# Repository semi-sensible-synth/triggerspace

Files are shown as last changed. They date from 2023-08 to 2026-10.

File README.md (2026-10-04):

# triggerspace

> **TESTED** - v0.042 works with some simple bodges (build notes below)
>
> **IN PROGRESS** - v0.5.0 removes the v0.042 bodges and adds optional RC reconstruction-cap
> sockets on the jack PCB's outputs to support alternative oscillators/sampler firmware; not yet fabricated or bench-verified (see
> [CHANGELOG.md](CHANGELOG.md))



This is a remix of the [NanoGris](https://github.com/Quinienl/NanoGris) trigger sequence generator (by Quinie), which in turn was based on the original [Grids](https://pichenettes.github.io/mutable-instruments-documentation/modules/grids/) hardware design by Mutable Instruments / Émilie Gillet, used under a Creative Commons ShareAlike 3.0 License (CC BY-SA 3.0).

The front panel looks something like this:

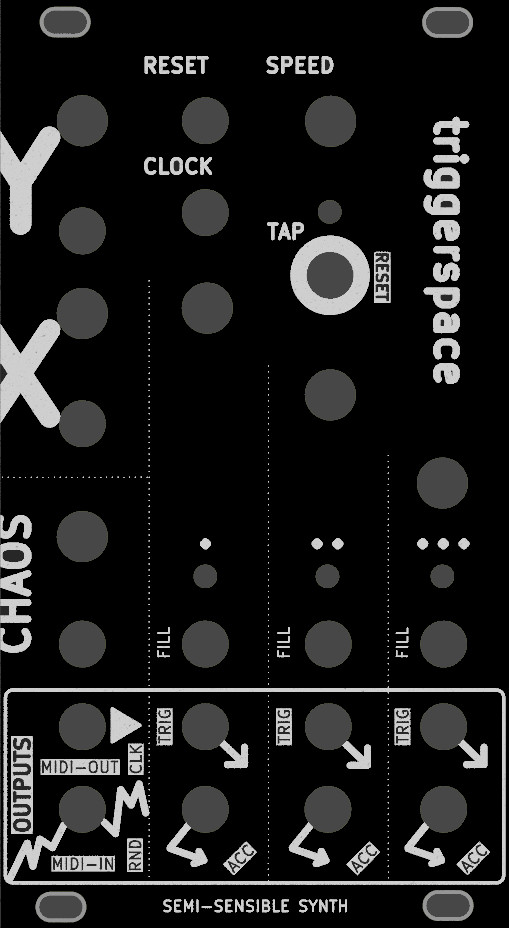
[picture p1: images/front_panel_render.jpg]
triggerspace front panel render Front panel


# Features
- Outputs three channels of 'topographic' drum triggers (kick, snare, hihat), with accent outputs
- Internal clock, with reset and swing
- External clock input, via triggers or MIDI clock
- Beat density (fill), X, Y and Chaos inputs to modify each pattern
- MIDI TRS-A output, General MIDI drum notes on channel 10
- MIDI TRS input accepts Type A and Type B (v0.5.0, [LPZW auto-crossover MIDI input](https://github.com/kay-lpzw/LPZW_TRS_MIDI))
- 38mA peak current draw on +12V rail (28mA idle)
- Experimental alternative firmwares: 6-voice oscillator [Gritty-osc](https://github.com/semi-sensible-synth/triggerspace/blob/main/firmware/Gritty-osc/README.md) and drum hit synth [Gritty-drumsynth](https://github.com/semi-sensible-synth/triggerspace/blob/main/firmware/Gritty-drumsynth/README.md)

## Firmware

_The stock Grids/NanoGris firmware is not compatible_ - use this: [Gritty-Grids firmware (triggerspace fork)](https://github.com/semi-sensible-synth/Gritty-Grids). Follow the instructions there to flash the firmware to your triggerspace module.

This Gritty-Grids fork:

- Supports modified Arduino Nano pin assignments used by _triggerspace_ hardware
- Sends General MIDI drum notes on channel 10 to MIDI-OUT (TRS-A)
  - GM MIDI (and Roland TR-8S) drum note numbers:
  ```
  Out 1:             36 (0x24, C1)  - bass/kick drum
  Out 2:             38 (0x26, D1)  - snare drum
  Out 3 (no accent): 42 (0x2a, F#1) - closed hi-hat
  Out 3 (accented):  46 (0x2e, Bb1) - open hi-hat
  ```
- Maps accents to MIDI note velocity: accented steps are sent at velocity 127 and
  unaccented steps at 90. Accented hi-hat steps also switch to the open hi-hat note (46).
  - Accents only exist in drum mode. With the clock output option on, Grids
    has a single common accent output, so that accent applies to all three drums.
  - In Euclidean mode there are no accents: every note is sent at velocity 127 as the
    closed hi-hat.
  - Set by `midi_accent_velocity` in `grids/grids.cc` (default on). When off, every note
    is sent at 127; the open/closed hi-hat switch still follows the accent. It can only
    be changed by recompiling for now.
  - Gritty-drumsynth sends MIDI notes the same way.

## Build options

### MIDI IN optocoupler (U8 / U9)

From v0.5.0 the MIDI input is the
[LPZW auto-crossover MIDI input](https://github.com/kay-lpzw/LPZW_TRS_MIDI) by Kay Knofe
of LPZW.modules.

It accepts TRS Type A and Type B cables with no switch. It works by using the two LEDs of a dual optocoupler in an 'anti-parallel' configuration across the tip and ring, each with its own 220R. Whichever way round the loop current flows, one LED lights, and the two open-collector outputs share one 1k pull-up (R47), so the Nano sees the same signal either way.

Fit one of these:

| Build | U8 (DIP-8 socket) | U9 (SOIC-8) | D7 | JP3, JP4 | Accepts |
|---|---|---|---|---|---|
| **Default** | HCPL-2630 or HCPL-2631 | not fitted | not fitted | as made (1-2 bridged) | Type A and B |
| SMD optocoupler | not fitted, no socket | HCPL-0630 or HCPL-0631 | not fitted | as made (1-2 bridged) | Type A and B |
| 6N138 (as v0.042) | 6N138 | not fitted | 1N4148 | cut 1-2, bridge 2-3 | Type A only |

- U9 sits inside U8's DIP-8 footprint on the back of the jack PCB, so fit U8 or U9,
  never both - a DIP socket would sit on top of U9. The HCPL-263x (DIP-8) and HCPL-063x
  (SOIC-8) have the same pinout.
- R46 (4.7k) is fitted in every build but only connected (through JP4) in the 6N138
  build, where it is the 6N138's base resistor. R51 is only used by the dual
  optocouplers; with a 6N138 it goes to an unconnected pin.
- D7 protects the 6N138's LED from reverse voltage. Don't fit it with a dual
  optocoupler: it would sit across one of the LEDs and take the current meant for the
  other, so Type B input would stop working.
- The HCPL-263x/063x is guaranteed to switch at 5mA LED current. A 5V MIDI 1.0 sender
  into a 220R receiver gives about 5mA, so worst-case parts are marginal (typical parts
  switch at about 2mA); 3.3V senders built to the MIDI Association's CA-33 values give
  about 7mA. The 6N138 needs only about 1.6mA, so it tolerates weaker Type A senders.

See [Jumpers](#jumpers) for JP3/JP4 to enable the 6N138 build (and other jumper settings).

### -5V reference: LM4040 or 5.1V zener (U5 / D8)

U5 (LM4040LP-5, TO-92) makes the -5V reference (`ref_5`) for the CV input offsets,
fed from -12V through R31 (10k). D8 is an alternative footprint in parallel with it for
a 5.1V zener diode (DO-35, e.g. BZX79C5V1 or 1N5231B), which worked well on a v0.042
build. Fit U5 or D8, not both.

- D8 sits inside U5's outline and is mounted upright: the diode body goes on the round
  pad with the cathode band at the top, and the bent lead goes into the square pad
  (marked K, to GND). The anode is on `ref_5`, because the reference is negative.
- R31 sets the zener current to about (12V - 5.1V) / 10k = 0.7mA. This is below the
  5-20mA test current of common 5.1V zeners, so expect a little less than 5.1V and a
  less stable voltage than the LM4040. The voltage shifts the CV input offsets slightly;
  it doesn't affect the triggers.

### +5V supply and power header (U4, JP5, JP6, J12)

The +5V rail (op amps, shift register, pots, trigger transistors) can come from one of
three sources. Use exactly one: don't connect two regulator outputs together.

| +5V source | U4, C11, C12 | JP5 | JP6 | Power cable |
|---|---|---|---|---|
| **U4 (L7805), default** | fitted | open | open | 10-pin or 16-pin |
| Nano's regulator | not fitted | bridged | open | 10-pin or 16-pin |
| Eurorack +5V | not fitted | open | bridged | 16-pin, from a PSU with +5V |

U4, C11 and C12 are marked "OPTIONAL" on the silkscreen. JP5 and JP6 are open as made.

- **Nano's regulator (JP5):** since v0.5.0 the Nano's VIN is fed from +12V, so its
  onboard 5V regulator is running anyway. JP5 connects the Nano's 5V pin (A1 pin 27) to
  the +5V rail, so that regulator supplies the whole module. The v0.042 module drew
  28-38mA from +12V in total, so the regulator dissipates about (12V - 5V) x 38mA =
  0.27W. With JP5 bridged, the Nano's USB port also powers the +5V rail when the module
  has no Eurorack power.
- **Eurorack +5V (JP6):** J12 is a 16-pin (2x8) footprint. Pins 11 and 12 are the
  Eurorack +5V rail, connected to the module's +5V rail through JP6. Pins 13-16 (CV and
  Gate buses) are not connected. With JP6 open, a 16-pin cable is safe whether or not
  the PSU provides +5V.
- **10-pin header in the 16-pin footprint:** a 2x5 header fits in J12 pins 1-10 (the
  end with the square pad, marked "RED!!" for the cable's -12V stripe), so 10-pin cables
  still work. The
  silkscreen outline is drawn for a 16-pin shrouded header; line up a 10-pin header's
  pin 1 with the square pad.

### RC reconstruction caps (CH*_CAP1)

The six 2-pin sockets next to the output jacks on the jack PCB (`CH1_CAP1`,
`CH1_ACC_CAP1`, `CH2_CAP1`, `CH2_ACC_CAP1`, `CH3_CAP1`, `CH3_ACC_CAP1`) take optional
capacitors to GND that filter the sigma-delta hiss from the Gritty-drumsynth firmware's
synthesised drum voices. Leave them empty for trigger outputs (Gritty-Grids firmware).
Values are still to be chosen (see TODO / IDEAS).

## Jumpers

Most solder jumpers (JP1-JP4) are shorted by a copper trace between their pads as made;
cut the trace with a craft knife to open them. JP5 and JP6 are open as made. Bridge pads
with solder to close a jumper. Pin
jumpers (J) are 2.54mm headers for jumper caps. Pin 1 of each header is the square pad.
The silkscreen next to each header repeats its settings.

Firmware and jack function settings, as shipped:

| Function | Gritty-Grids firmware (MIDI, default) | Stock Grids/NanoGris firmware (triggers) |
|---|---|---|
| Clock input to the Nano | JP2 bridged (clock on D8) | cut JP2, fit J2 (clock on D1) |
| Nano D1/TX | JP1 bridged (D1 drives MIDI OUT) | cut JP1, fit J1 (see below) |
| CLOCK / MIDI OUT jack | J6 1-2, J3 3-4 (optionally also J3 1-2) | J6 2-3, J3 1-2 |
| RND / MIDI IN jack | J8 2-3, J5 1-2, J4 3-4 | J8 1-2, J5 2-3, J4 1-2 |
| +5V source | U4 fitted, JP5 and JP6 open | same |

The jack settings are independent of the firmware: with Gritty-Grids you can still set
either jack back to a trigger output, and the MIDI clock or MIDI notes on that port are
then lost.

### Back PCB

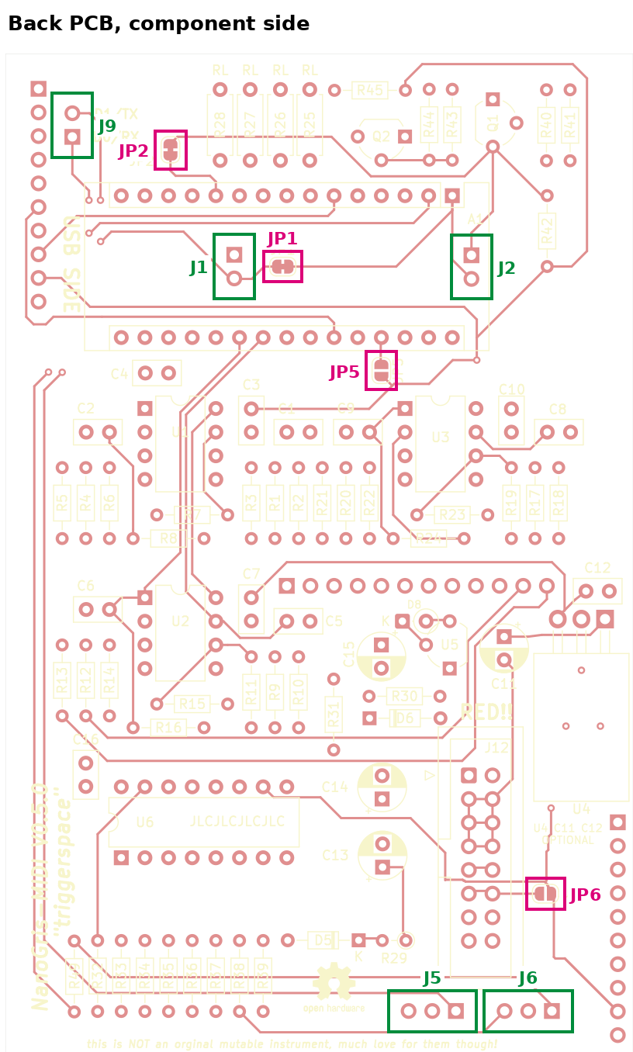
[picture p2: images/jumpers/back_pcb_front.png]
Back PCB jumper locations Back PCB jumpers


- **JP1** (bridged) connects Nano D1/TX to the MIDI OUT line (`OUT_MIDI`, through R49
  to the jack). **JP2** (bridged) connects the clock input transistor (Q1) to D8. Both
  stay bridged for Gritty-Grids.
- **J1** connects D8 to the MIDI OUT line and **J2** connects the clock input to D1.
  The silkscreen instruction for stock firmware is "cut JP1 & JP2, bridge jumper J1,
  J2": the clock input then reaches D1, where the stock firmware reads it, and D1 is no
  longer connected to the MIDI OUT line. Don't fit J1 or J2 with JP1 and JP2 still
  bridged.
- **J5** (3-pin, to the RND / MIDI IN jack via the jack PCB): 1-2 = MIDI IN (optocoupler
  output to D0/RX), 2-3 = RND trigger output.
- **J6** (3-pin, to the CLOCK / MIDI OUT jack via the jack PCB): 1-2 = MIDI OUT (D1/TX
  through R49), 2-3 = CLOCK trigger output.
- **J9** (2-pin, silkscreen "MIDI IN" / "MIDI OUT"): pin 1 = D0/RX, pin 2 = D1/TX
  (logic level, before R49). Use it to wire up a different MIDI interface (e.g. a DIN
  socket board). If you feed a MIDI signal into pin 1, remove the J5 jumper so the
  optocoupler output doesn't drive the same line.
- **JP5** (open, below the Nano): bridge to power the +5V rail from the Nano's
  regulator. **JP6** (open, next to J12): bridge to power the +5V rail from the Eurorack
  +5V on a 16-pin cable. Fit U4, C11 and C12 only if both are open. See
  [+5V supply and power header](#5v-supply-and-power-header-u4-jp5-jp6-j12).

### Jack PCB

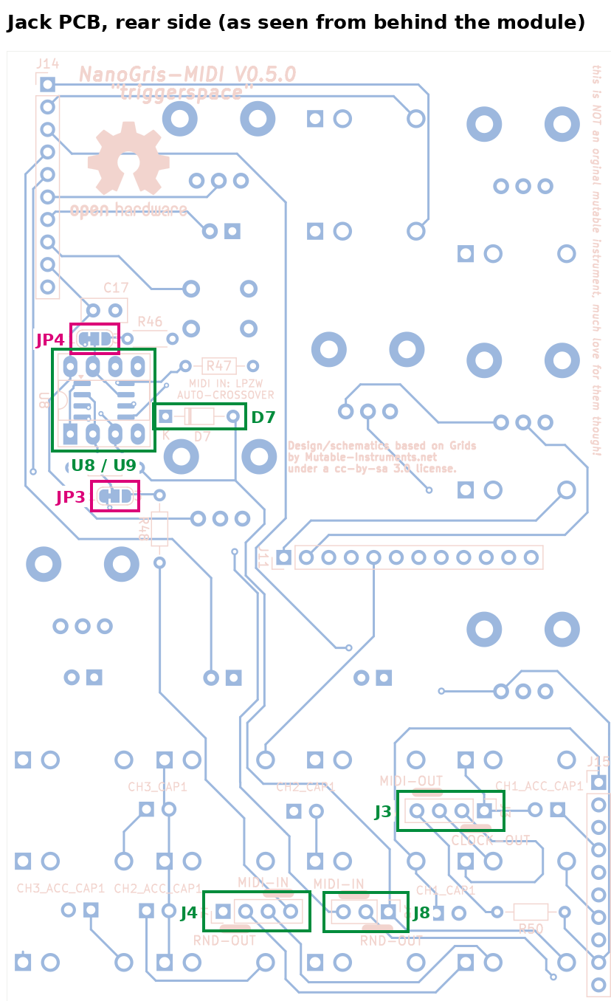
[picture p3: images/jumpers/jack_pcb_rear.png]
Jack PCB jumper locations Jack PCB jumpers


- **J3** (4-pin, CLOCK / MIDI OUT jack): 1-2 connects the sleeve to GND, 3-4 connects the
  ring to +5V through R50. CLOCK OUT: 1-2. MIDI OUT: 3-4; also fit 1-2 so the sleeve
  (cable shield) is grounded at the sending end, as the MIDI specification asks.
- **J4** (4-pin, RND / MIDI IN jack): 1-2 connects the sleeve to GND, 3-4 connects the
  ring to the optocoupler. RND OUT: 1-2. MIDI IN: 3-4 only; leave 1-2 open, since a MIDI
  receiver must not ground the cable shield.
- **J8** (3-pin, RND / MIDI IN jack tip): 1-2 = RND trigger output to the tip, 2-3 =
  optocoupler output to the back PCB (MIDI IN).
- **JP3** and **JP4** (3-pad solder jumpers, 1-2 bridged as made) select the MIDI IN
  optocoupler type. Leave them as made for the dual optocoupler (HCPL-263x in U8, or
  HCPL-063x in U9). For a 6N138, cut 1-2 and bridge 2-3 on both, and fit D7. See
  [MIDI IN optocoupler](#midi-in-optocoupler-u8--u9).
  - JP3 pad 2 goes to U8 pin 2 (HCPL-263x: LED 1 cathode; 6N138: LED anode). Pad 1 =
    jack ring (dual optocoupler), pad 3 = the R48 / D7 node (6N138).
  - JP4 pad 2 goes to U8 pin 7 (HCPL-263x: output 1; 6N138: transistor base). Pad 1 =
    the shared output and R47 pull-up (dual optocoupler), pad 3 = R46 4.7k to GND
    (6N138).

## Changelog

See [CHANGELOG.md](CHANGELOG.md) for the changes in each hardware revision.

## v0.042 build guide notes (bodges required !)

  - Trying to power the Nano via 5V from U4 voltage regulator to VIN pin 30 didn't work here, despite the original NanoGris design doing it this way. Upon reflection this is no surprise ... 5V isn't enough for the typical AMS1117-5.0 regulator found on a Nano (clone), which needs ~>= 6.5V input to work ! I fixed this with a bodge as follows:
    - Melt the VIN pin 30 solder joint and push it 'up' so it doesn't insert into the female header. This disconnects the Nano from the U4 regulator, but still allows U4 to power the 5V rail in the rest of the module.
    - Attach a bodge wire from the +12V rail pin on the U4 voltage regulator to the protruding VIN pin 30 (I used a single female header to make it easy to remove the Nano if required).
  - I didn't have an LM4040-5.0 on hand, but a 5.1V Zener diode seems to work well enough. From v0.5.0 it has its own footprint (D8, see [Build options](#build-options)).
  - Can optionally use an 78L50 (TO-92) voltage regulator rather than L7805 (TO-220)
  - Sometimes flashing the firmware seems to fail (can't connect to device) when the Nano is in the module, but seems to work if you take out out of the PCB to flash ¯\_(ツ)_/¯

## Modifications from the original NanoGris module

- Added MIDI-IN TRS-A jack + 6N137 optocoupler for MIDI clock sync. The original Grids always had this option as an extra jumper on the PCB - now it's broken out onto a more cluttered front panel !
- Added MIDI-OUT TRS-A - required changing the pin used for the clock in to allow use of hardware serial TX/RX, so this modules requires [custom firmware](https://github.com/semi-sensible-synth/Gritty-Grids) even if you aren't using the MIDI-OUT option.
  - I've added pin jumpers and cuttable solder jumpers to allow re-routing for stock firmware if required/desired.
- The CLOCK and RND outputs are repurposed as the TRS-A MIDI-OUT and MIDI-IN ports, respectively. Several pin jumpers can be used to choose if these act as MIDI ports or the original voltage-based trigger outputs.
- Made more space between the FILL knobs (closer to original Grids layout), use a tactile button and cap for TAP button, various tweaks to routing and front panel design

## TODO / IDEAS

- Fabricate and bench-verify v0.5.0.
- Choose the RC reconstruction-cap values (and confirm the socket footprint) by bench
  testing with the Gritty-drumsynth firmware.
- Bench-test the +5V supply options (JP5: Nano regulator, JP6: Eurorack +5V) without
  U4.
- Do we have room for mute switches/buttons on each channel ?
- Now that we are using a full 8x2 IDC power socket - can we also (optionally) connect the CV/GATE pins (eg to clock), or follow the Disting Select Bus protocol to use it for MIDI ?

### Future firmware ideas

- Disting Ex SD 6 Triggers mode, where notes span 48-53 (unaccented and accented)
- Chord/arp output over MIDI. Set the chord root/inversion to be played via one of the CV inputs, or MIDI-IN
  - Read MIDI notes from MIDI-IN, buffer the last 3 or 6 notes seen and play these for Out1-3, Accent 1-3
- (Crazier ideas: pair it with a SAM2695 or VS1053B based module/expander for GM MIDI audio out ! There seem to be NOS versions on AliExpress ....)

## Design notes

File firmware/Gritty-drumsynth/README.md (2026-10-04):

# Gritty-drumsynth

A **synthesised drum-machine** firmware for the *triggerspace* (NanoGris-MIDI)
Eurorack module. It keeps Grids' topographic drum **sequencer**, clock and MIDI,
but replaces the raw voltage-trigger outputs with three internally **synthesised
808/909-style drum voices** — kick, snare and hat — rendered as 1-bit PDM on the
BD/SD/HH jacks.

Lineage: Mutable Instruments **Grids** (Émilie Gillet) → **Gritty-Grids** (Sonic
Insurgence, improved MIDI) → **triggerspace** pin remap (Andrew Perry) → this
synth fork. GPLv3.

> This firmware is **mandatory** for triggerspace — the PCB moves the clock input
> off D1 onto D8, freeing the D0/D1 UART for TRS-A MIDI, so stock Grids firmware
> will not run unmodified. To run on original Grids hardware instead, set
> `TRIGGERSPACE_PINOUT 0` in `grids/hardware_config.h` (moves the clock back to D1;
> MIDI is then unavailable).

## How it sounds / signal path

Each drum jack carries a **1-bit sigma-delta (PDM)** bitstream at a 31.25 kHz
carrier. The voices are true synthesis (DDS sine + LFSR noise + exponential
envelopes), oversampled by the modulator, so a clean low kick is possible from a
single output pin.

**The raw output is a 5 V 1-bit stream and sounds fuzzy on its own** — it needs a
low-pass to reconstruct. Options:

- Patch each jack through a Eurorack **filter/VCA** module, or
- Fit a tiny **RC "dongle"** on the jack: the ~1 kΩ series resistor already on
  the board + a small cap to ground (≈ 1–10 nF → ~16–80 kHz corner) tames the
  carrier. This is the only outstanding hardware item; everything else is
  software.

Outputs are 5 V logic level — AC-couple / attenuate for a Eurorack audio input.

## Controls

A **long-hold on the TAP button** (~0.5 s) cycles three edit pages:

```
PERFORM ──hold──▶ META ──hold──▶ VOICE ──hold──▶ PERFORM (saves on the way out)
 (play)      (Grids meta-params)  (drum tuning)
```

The clock, sequencer and audio **keep running in every page**, so edits preview
live on the playing pattern.

### PERFORM (normal play) — stock Grids performance UI

| Control | Function |
|---|---|
| **BD / SD / HH density** | Per-instrument hit density (fill) |
| **X** | Map position X (pattern morph) |
| **Y** | Map position Y (pattern morph) |
| **Randomness** | Pattern chaos **+ per-hit humanisation** (see below) |
| **Tempo** | Internal BPM. Fully left = external/MIDI clock mode |
| **TAP (short)** | Tap tempo / reset; mute-unmute in MIDI-clock mode |
| **Clock / Reset in** | External clock & reset (voltage-trigger jumper mode) |

### VOICE (drum tuning) — the six knobs edit **one voice at a time**

Enter with two long-holds. A **short TAP cycles the target voice** BD → SD → HH;
the selected voice's channel LED **blinks** (with the CLOCK LED lit) to show which
one you're editing. Knobs use *catch* behaviour — a knob only takes over once you
move it. Changes are **saved to EEPROM** when you long-hold back to PERFORM.

| Knob | Parameter | Kick (BD) | Snare (SD) | Hat (HH) |
|---|---|---|---|---|
| **BD density** | Pitch (~20 Hz–2 kHz) | body pitch | body pitch | metal-tone pitch |
| **SD density** | Body/amp length (~16–320 ms) | decay | body decay | — |
| **HH density** | Pitch-env depth | "punch" (sweep) | — | — |
| **X** | Tonal level | — | body vs noise | **noise↔metal blend** |
| **Y** | Noise level | — | snare noise | overall hat level |
| **Randomness** | Noise length (~16–320 ms) | — | noise tail | hat decay |
| **Tempo** | Pitch-env time | kick sweep time | — | — |

Notes: the kick is a pitch-swept sine (no noise); the snare is a sine body + a
high-passed-noise layer; the hat is high-passed noise blended with a cheap
two-oscillator **metallic tone** (turn **X** up on the hat to bring in the 808-ish
clang, set its pitch with **BD density**). A "—" means that param doesn't apply to
that voice.

### META (Grids meta-parameters)

Enter with one long-hold. Move a knob to set its parameter (LEDs indicate state):

| Knob | Meta-parameter |
|---|---|
| **BD density** | Clock resolution |
| **SD density** | Tap-tempo on/off |
| **HH density** | Swing on/off |
| **X** | Output mode (drums / accent-clock-reset) |
| **Y** | Gate mode |
| **Randomness** | Clock output on/off |

Accents (the louder accent layer on the voices, and the MIDI note-out velocity) only
exist in drum output mode. With clock output on, Grids has a single common accent, so it
applies to all three voices. In Euclidean mode no hits are accented.

## Per-hit humanisation (Randomness knob)

In PERFORM mode the Randomness knob does double duty: besides pattern chaos it
injects **per-hit variation** into the voices, scaled by the knob (fully left =
identical hits):

- **Pitch:** ±2% max, and only across the **top ~80%** of the knob's travel (the
  bottom fifth leaves pitch locked).
- **Level (velocity)** and **decay length:** up to **±20%**.

## MIDI

MIDI I/O is on the TRS jacks (D0/D1, 31250 baud). Drum channel is **10**.

- **Clock sync:** responds to MIDI Start / Stop / Continue / Clock (turn Tempo
  fully left to enter external/MIDI clock mode; TAP mutes/unmutes).
- **Note-in triggers voices** (independent of the sequencer): note **36** = kick,
  **38** = snare, **42** = closed hat, **46** = open hat (plus GM neighbours).
  Velocity ≥ 96 fires the accent layer.
- **Note-out:** the sequencer also sends GM drum notes (36/38/42/46) on ch 10.
  Accented steps are sent at velocity 127 and unaccented at 90, and accented hats use
  the open hat note (46). Set by `midi_accent_velocity` in `grids/grids.cc` (default
  on; when off every note is sent at 127).
- **CC live voice tuning** (any time, independent of edit page):

  | CC | Parameter | CC | Parameter |
  |----|-----------|----|-----------|
  | 20 | Kick pitch | 24 | Snare noise mix |
  | 21 | Kick decay | 25 | Snare noise decay |
  | 22 | Snare tone (body pitch) | 26 | Hat decay (open/closed) |
  | 23 | Snare body decay | 27 | Hat level |

## Build & flash

AVR C++ for ATmega328P at **16 MHz** (the board's actual crystal — already set in
the `makefile`). From this directory:

```bash
rm -rf build && make            # -> build/grids/grids.hex   (make clean leaves stale objects)
```

Flash with a **USBasp** ISP programmer (the Nano serial bootloader does not work
on this board — `-c arduino`/ttyUSB0 always fails):

```bash
avrdude -C /etc/avrdude.conf -p atmega328p -c usbasp \
        -U flash:w:build/grids/grids.hex:i
```

Flashing can fail with the Nano seated in the module — pull it out to flash if
needed. On Ubuntu, `brltty` may grab a CH34x USB device; stop/mask it first.

### Diagnostics

`grids.cc` has a `//#define DRUMSYNTH_TEST_TONE` near the top: uncomment it to
force a continuous 220 Hz tone on all three jacks, bypassing the sequencer — handy
for verifying the audio ISR / PDM / output path in isolation. Leave it commented
for normal use.

## Credits & license

- Original **Grids** design and code: **Émilie Gillet**, Mutable Instruments —
  released open source, with thanks.
- **Gritty-Grids** MIDI improvements: **Sonic Insurgence**.
- triggerspace remap & **Gritty-drumsynth**: **Andrew Perry**.

GPLv3 — this program is free software; redistribute/modify under the GNU General
Public License v3 or (at your option) any later version.

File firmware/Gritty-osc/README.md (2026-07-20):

# Gritty-osc

A **six-voice oscillator** firmware for the *triggerspace* (NanoGris-MIDI)
Eurorack module. Unlike [Gritty-drumsynth](../Gritty-drumsynth), it **drops the
drum sequencer** and turns the module into a polyphonic square/pulse (PWM) DDS
oscillator with a built-in chord engine and arpeggiator, playable from the panel
knobs and CV inputs — or from MIDI (build-time modes, see [MIDI](#midi-build-time)).

Lineage: Mutable Instruments **Grids** (Émilie Gillet) → **Gritty-Grids** (Sonic
Insurgence) → **triggerspace** pin remap (Andrew Perry) → this oscillator fork.
GPLv3.

> Since the triggerspace hardware remaps the Nano pins (clock moved off D1 to D8,
> freeing the D0/D1 UART for MIDI), this firmware will not run unmodified on stock
> Grids or clones. Set `TRIGGERSPACE_PINOUT 0` in `grids/hardware_config.h` to
> build for original Grids hardware (clock back on D1; MIDI then unavailable).

## How it sounds / signal path

Six independent **DDS voices** (16-bit phase accumulators), each packed into one
bit of the 74HC595 and shifted out at **Fs = 62.5 kHz**. Each output is 1-bit, so
every jack is a **pulse/square** — pitch is exact (DDS), and the only continuous
per-voice timbre control is **PWM duty** (50% = square). Clean to a few kHz,
usable to ~8 kHz (about 5–6 octaves).

Output routing (matches the Grids state byte / jack wiring):

| Jack (bit) | Voice |
|---|---|
| CH1 `0x01` / CH2 `0x02` / CH3 `0x04` | Main voices 0 / 1 / 2 |
| CH1_ACC `0x08` / CH2_ACC `0x10` / CH3_ACC `0x20` | Voices 3 / 4 / 5 = **sub-octaves** of the mains |
| CLOCK `0x40` | **PDM mono mix** of all six voices (1-bit sigma-delta) |
| RND `0x80` | unused |

The **mix on the CLOCK jack** only works with that jack's PCB jumper in
voltage-trigger (not MIDI) mode; low-pass it externally (the ~1 kΩ series R + a
small cap, e.g. 1–2.2 nF, cleans up the carrier). All outputs are 5 V logic —
filter / AC-couple / attenuate for Eurorack audio.

## Controls (default build — "Option B")

| Control | Function |
|---|---|
| **Y** knob + CV | Root pitch |
| **Randomness (chaos)** knob + CV | Chord type (8: unison "superpulse" / power / maj / min / sus4 / …) |
| **BD / SD / HH density** knobs | Per-channel **PWM duty** of the three chord tones |
| **X** knob + CV | Detune — first half spreads the sub-octaves, second half also detunes the mains (ensemble / supersaw) |
| **Tempo** | Arp range, 1–4 octaves (ARP trigger mode only) |
| **CLOCK in (D8)** | Arp **step** (advance) |
| **RESET in (D2)** | Arp **reset** to step 0 |
| **Button (D3)** | Cycle arp **direction mode** (readout on LEDs, 1–6) |

CV inputs sum into the pots, so every knob parameter is also CV-modulatable.

### Trigger function (build-time)

The CLOCK / RESET / button inputs drive one of three behaviours, selected by a
`#define` in `grids.cc` (default `OSC_TRIG_ARP`):

- **`OSC_TRIG_ARP`** — CLOCK steps through the chord tones across octaves (chord =
  the note pool); all six voices play the stepping note. TEMPO sets the range
  (1–4 oct). The button cycles direction: up / down / up-down inclusive / up-down
  exclusive / random / random-walk, shown on the LEDs as 1–6. RESET restarts.
- **`OSC_TRIG_ROTATE`** — chord keeps sounding; each step rotates the voicing /
  inversion.
- **`OSC_TRIG_PLUCK`** — chord keeps sounding; each step fires a decaying
  PWM-duty envelope (percussive re-articulation).

### Alternate mapping (build-time)

Define **`OSC_DENSITY_AS_PITCH`** to switch from the chord engine to independent
per-channel pitch: the three density knobs become per-channel pitch, TEMPO becomes
transpose (±2 oct), X becomes a global PWM duty, and Y / chaos are unused.

## Pitch / tuning

Pitch comes from a precomputed **note → tuning-word table** (equal temperament,
generated for Fs = 62.5 kHz) — no floating-point `powf` at runtime, just a flash
lookup. Verified against a tuner on the 16 MHz board.

## MIDI (build-time)

The six voices can be played from the **D0/D1 TRS-A MIDI input** instead of the
knob/CV + trigger control. Define **exactly one** `OSC_MIDI_*` mode near the top
of `grids.cc` (all are commented out by default = the knob/arp oscillator above).
MIDI needs `TRIGGERSPACE_PINOUT` (the D0/D1 UART); the trigger/arp handling is
compiled out in a MIDI build.

| Mode `#define` | Behaviour |
|---|---|
| **`OSC_MIDI_MONO_ROOT`** (A) | One channel. The (last) held note sets the **root**; the panel still shapes it — chaos = chord type, X = detune, density knobs = per-channel PWM. A full six-voice chord from a single key. |
| **`OSC_MIDI_MULTI_3CH`** (B) | Three channels (base, base+1, base+2) drive **osc 0 / 1 / 2** independently; each sub-oscillator tracks its main an octave down. |
| **`OSC_MIDI_POLY3`** (C1) | **3-voice** polyphony, notes round-robined over osc 0/1/2; each sub doubles its main an octave down. |
| **`OSC_MIDI_POLY6`** (C2) | **6-voice** polyphony, notes round-robined over all six oscillators (subs are independent voices, no doubling). |
| **`OSC_MIDI_SPLIT`** (D) | **Split keyboard**: notes ≥ `OSC_SPLIT_NOTE` round-robin over the mains (0/1/2); notes below are a bassline round-robined over the subs (3/4/5). |

Config `#define`s (also in `grids.cc` / `hardware_config.h`):

- **`OSC_MIDI_CHANNEL`** — base MIDI channel, 0-based (`0` = channel 1). Mode B
  also uses `base+1` and `base+2`.
- **`OSC_SPLIT_NOTE`** — split point for mode D, as a MIDI note (`48` = C3, with
  60 = middle C/C4). Try `60` if that suits the keyboard.

Voice allocation prefers a free voice, else steals round-robin. A released note
silences its voice (its pulse width drops to zero — no audio) rather than gating
an envelope (there is no VCA/envelope yet). The **firing channel's LED blinks**
on each note (`OSC_LED_FLASH_LOOPS` sets the length), so the round-robin
allocation reads as the BD/SD/HH LEDs cycling. The clock-jack mix is unchanged.
Common CCs:

| CC | Function |
|----|---|
| **1** (mod wheel) | Global **PWM duty** (0 = square → up = thinner/brighter). No internal LFO yet, so the mod wheel drives PWM instead of vibrato. |
| **94** (detune depth) | Detune amount in modes A/B (spreads main vs sub). |
| **123** (all notes off) | Silences all voices. |

> Note velocity, pitch bend and per-voice envelopes are not handled yet; these
> modes are a first pass (see `plans/gritty-osc.md`).

## Build & flash

AVR C++ for ATmega328P at **16 MHz** (already set in the `makefile`). From this
directory:

```bash
rm -rf build && make            # -> build/grids/grids.hex   (make clean leaves stale objects)
```

Flash with a **USBasp** ISP programmer (the Nano serial bootloader does not work
on this board):

```bash
avrdude -C /etc/avrdude.conf -p atmega328p -c usbasp \
        -U flash:w:build/grids/grids.hex:i
```

Flashing can fail with the Nano seated in the module — pull it out to flash if
needed. On Ubuntu, `brltty` may grab a CH34x USB device; stop/mask it first.

## Credits & license

- Original **Grids** design and code: **Émilie Gillet**, Mutable Instruments —
  released open source, with thanks.
- **Gritty-Grids** MIDI improvements: **Sonic Insurgence**.
- triggerspace remap & **Gritty-osc**: **Andrew Perry**.

GPLv3 — this program is free software; redistribute/modify under the GNU General
Public License v3 or (at your option) any later version.

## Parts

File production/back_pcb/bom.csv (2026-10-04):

Designator | Footprint | Quantity | Value | DNP
A1 | Module:Arduino_Nano | 1 | Arduino_Nano_v2.x
C1,C2,C5,C6,C8,C9,C12 | Capacitor_THT:C_Disc_D5.0mm_W2.5mm_P2.50mm | 7 | 10nf
C3,C4,C7,C10,C16 | Capacitor_THT:C_Disc_D5.0mm_W2.5mm_P2.50mm | 5 | 100nf
C11,C15 | Capacitor_THT:CP_Radial_D5.0mm_P2.50mm | 2 | 0.47uf
C13,C14 | Capacitor_THT:CP_Radial_D5.0mm_P2.50mm | 2 | 10uf
J1,J2,J9 | Connector_PinSocket_2.54mm:PinSocket_1x02_P2.54mm_Vertical | 3 | Conn_01x2
D5,D6 | Diode_THT:D_DO-34_SOD68_P7.62mm_Horizontal | 2 | 1N5817
D8 | Diode_THT:D_DO-35_SOD27_P2.54mm_Vertical_KathodeUp | 1 | 5.1V | DNP
FID1 | Symbol:OSHW-Logo2_7.3x6mm_SilkScreen | 1 | Fiducial
H1 | MountingHole:MountingHole_3.2mm_M3 | 1 | MountingHole
J5,J6 | Connector_PinHeader_2.54mm:PinHeader_1x03_P2.54mm_Vertical | 2 | Conn_01x3
J7,J13 | Connector_PinSocket_2.54mm:PinSocket_1x10_P2.54mm_Vertical | 2 | Conn_01x10
J10 | Connector_PinSocket_2.54mm:PinSocket_1x12_P2.54mm_Vertical | 1 | Conn_01x12
J12 | Connector_IDC:IDC-Header_2x08_P2.54mm_Vertical | 1 | Eurorack power 2x8 (or 2x5)
JP1,JP2 | Jumper:SolderJumper-2_P1.3mm_Bridged_RoundedPad1.0x1.5mm | 2 | SolderJumper_2_Bridged
Q1,Q2 | Package_TO_SOT_THT:TO-92_Wide | 2 | 2N3904
R1,R2,R3,R4,R5,R6,R7,R8,R9,R10,R11,R12,R13,R14,R15,R16,R17,R18,R19,R20,R21,R22,R23,R24,R40,R41,R42,R43,R44,R45 | Resistor_THT:R_Axial_DIN0204_L3.6mm_D1.6mm_P7.62mm_Horizontal | 30 | 100k
R25,R26,R27,R28 | Resistor_THT:R_Axial_DIN0207_L6.3mm_D2.5mm_P7.62mm_Horizontal | 4 | 4.7k
R29 | Resistor_THT:R_Axial_DIN0204_L3.6mm_D1.6mm_P2.54mm_Vertical | 1 | 10r
R30 | Resistor_THT:R_Axial_DIN0204_L3.6mm_D1.6mm_P7.62mm_Horizontal | 1 | 10r
R31 | Resistor_THT:R_Axial_DIN0204_L3.6mm_D1.6mm_P7.62mm_Horizontal | 1 | 10k
R32,R33,R34,R35,R36,R37,R38,R39 | Resistor_THT:R_Axial_DIN0204_L3.6mm_D1.6mm_P7.62mm_Horizontal | 8 | 1k
R49 | Resistor_THT:R_Axial_DIN0204_L3.6mm_D1.6mm_P7.62mm_Horizontal | 1 | 220
U1,U2,U3 | Package_DIP:DIP-8_W7.62mm | 3 | MCP6002_1
U4 | Package_TO_SOT_THT:TO-220-3_Horizontal_TabDown | 1 | L7805
U5 | Package_TO_SOT_THT:TO-92_Wide | 1 | LM4040LP-5
U6 | Package_DIP:DIP-16_W7.62mm | 1 | 74HC595

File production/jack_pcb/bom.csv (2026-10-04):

Designator | Footprint | Quantity | Value | DNP
C17 | Capacitor_THT:C_Disc_D5.0mm_W2.5mm_P2.50mm | 1 | 100nf
CH1 | Connector_Audio:Jack_3.5mm_QingPu_WQP-PJ398SM_Vertical_CircularHoles | 1 | CH1
CH1_AC1 | Connector_Audio:Jack_3.5mm_QingPu_WQP-PJ398SM_Vertical_CircularHoles | 1 | CH1_ACC
CH1_ACC_CAP1,CH1_CAP1,CH2_ACC_CAP1,CH2_CAP1,CH3_ACC_CAP1,CH3_CAP1 | Connector_PinSocket_2.54mm:PinSocket_1x02_P2.54mm_Vertical | 6 | Conn_01x2
CH1_FILL1 | Connector_Audio:Jack_3.5mm_QingPu_WQP-PJ398SM_Vertical_CircularHoles | 1 | CV_CH1
CH2 | Connector_Audio:Jack_3.5mm_QingPu_WQP-PJ398SM_Vertical_CircularHoles | 1 | CH2
CH2_AC1 | Connector_Audio:Jack_3.5mm_QingPu_WQP-PJ398SM_Vertical_CircularHoles | 1 | CH2_ACC
CH2_FILL1 | Connector_Audio:Jack_3.5mm_QingPu_WQP-PJ398SM_Vertical_CircularHoles | 1 | CV_CH2
CH3 | Connector_Audio:Jack_3.5mm_QingPu_WQP-PJ398SM_Vertical_CircularHoles | 1 | CH3
CH3_AC1 | Connector_Audio:Jack_3.5mm_QingPu_WQP-PJ398SM_Vertical_CircularHoles | 1 | CH3_ACC
CH3_FILL1 | Connector_Audio:Jack_3.5mm_QingPu_WQP-PJ398SM_Vertical_CircularHoles | 1 | CV_CH3
CLOCK1 | Connector_Audio:Jack_3.5mm_QingPu_WQP-PJ398SM_Vertical_CircularHoles | 1 | CV_CLOCK
D1 | LED_THT:LED_D3.0mm | 1 | CH1
D2 | LED_THT:LED_D3.0mm | 1 | CH2
D3 | LED_THT:LED_D3.0mm | 1 | CH3
D4 | LED_THT:LED_D3.0mm | 1 | CLK
D7 | Diode_THT:D_DO-34_SOD68_P7.62mm_Horizontal | 1 | 1n4148 | DNP
FID2 | Symbol:OSHW-Logo2_14.6x12mm_SilkScreen | 1 | Fiducial
H2 | MountingHole:MountingHole_3.2mm_M3 | 1 | MountingHole
J3,J4 | Connector_PinHeader_2.54mm:PinHeader_1x04_P2.54mm_Vertical | 2 | Conn_01x4
J8 | Connector_PinHeader_2.54mm:PinHeader_1x03_P2.54mm_Vertical | 1 | Conn_01x3
J11 | Connector_PinHeader_2.54mm:PinHeader_1x12_P2.54mm_Vertical | 1 | Conn_01x12
J14,J15 | Connector_PinHeader_2.54mm:PinHeader_1x10_P2.54mm_Vertical | 2 | Conn_01x10
MIDI_IN_RND_OUT1 | Connector_Audio:Jack_3.5mm_QingPu_WQP-PJ398SM_Vertical_CircularHoles | 1 | MIDI_IN_RND
MIDI_OUT_CLOCK_OUT1 | Connector_Audio:Jack_3.5mm_QingPu_WQP-PJ398SM_Vertical_CircularHoles | 1 | MIDI_OUT-CLOCK_OUT
P_CH1,P_CH2,P_CH3,P_RND1,P_TEMPO1,P_X1,P_Y1 | Potentiometer_THT:Potentiometer_Alps_RK09K_Single_Vertical_round | 7 | 10k
R47 | Resistor_THT:R_Axial_DIN0204_L3.6mm_D1.6mm_P7.62mm_Horizontal | 1 | 1k
R46 | Resistor_THT:R_Axial_DIN0204_L3.6mm_D1.6mm_P5.08mm_Horizontal | 1 | 4.7k
R48,R50,R51 | Resistor_THT:R_Axial_DIN0204_L3.6mm_D1.6mm_P7.62mm_Horizontal | 3 | 220
RESET1 | Connector_Audio:Jack_3.5mm_QingPu_WQP-PJ398SM_Vertical_CircularHoles | 1 | CV_RESET
RESET2 | Button_Switch_THT:SW_PUSH_6mm | 1 | SW_Push
RND2 | Connector_Audio:Jack_3.5mm_QingPu_WQP-PJ398SM_Vertical_CircularHoles | 1 | CV_RND
U8 | Package_DIP:DIP-8_W7.62mm_Socket_LongPads | 1 | HCPL-2630
U9 | Package_SO:SOIC-8_3.9x4.9mm_P1.27mm | 1 | HCPL-0630 | DNP
X1 | Connector_Audio:Jack_3.5mm_QingPu_WQP-PJ398SM_Vertical_CircularHoles | 1 | CV_X
Y1 | Connector_Audio:Jack_3.5mm_QingPu_WQP-PJ398SM_Vertical_CircularHoles | 1 | CV_Y

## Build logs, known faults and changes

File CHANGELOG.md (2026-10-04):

# Changelog

All notable changes to this project will be documented in this file.

The format is based on [Keep a Changelog](https://keepachangelog.com/en/1.1.0/).

v0.5.0 is still in progress: changes are added to it until it is fabricated and
bench-verified.

## [0.5.0] - In progress

Not yet fabricated or bench-verified.

### Added

- RC reconstruction-cap sockets (`CH1_CAP1`, `CH1_ACC_CAP1`, `CH2_CAP1`, `CH2_ACC_CAP1`,
  `CH3_CAP1`, `CH3_ACC_CAP1`) on the jack PCB's six outputs, to filter the sigma-delta
  hiss from the Gritty-drumsynth firmware's synthesised drum voices.
- "RL" silkscreen labels on the LED resistors R25-R28, so they are easy to find and
  change.
- "MIDI IN"/"MIDI OUT" labels on the back silkscreen for the back PCB's 2-pin MIDI
  header (J9).
- Aluminium front-panel fabrication outputs (`production/front_panel_aluminium/`) and
  panel cutout artwork (`svg/`).
- `firmware/` directory: the [Gritty-Grids](https://github.com/semi-sensible-synth/Gritty-Grids)
  firmware as a git submodule, plus two in-tree forks - Gritty-drumsynth (synthesised
  808/909-style drum voices on the output jacks) and Gritty-osc (six-voice DDS chord
  oscillator with arpeggiator and MIDI note control).
- MIDI IN accepts both TRS Type A and Type B, using the
  [LPZW auto-crossover MIDI input](https://github.com/kay-lpzw/LPZW_TRS_MIDI) by Kay
  Knofe of LPZW.modules (credited on the jack PCB silkscreen). U8 is now a dual
  optocoupler (HCPL-2630) whose two LEDs are anti-parallel across tip and ring, each
  with its own 220R (R48 and the new R51).
- U9: optional SOIC-8 footprint (HCPL-0630) inside U8's DIP-8 footprint, for builds
  that use the SMD part instead of the DIP-8 one. Fit U8 or U9, not both.
- Solder jumpers JP3 and JP4 (default pads 1-2 bridged) so the board can still be built
  with a 6N138 in U8 as before: cut 1-2, bridge 2-3 and fit D7. See "Build options" in
  the README.
- +5V supply options: JP5 (open) connects the Nano's 5V output (A1 pin 27) to the +5V
  rail, and JP6 (open) connects the Eurorack +5V (power header pins 11/12) to it, so
  U4, C11 and C12 can be left out. They are marked "OPTIONAL" on the silkscreen. See
  "Build options" in the README.
- J12 (power header) is now a 16-pin (2x8) footprint; a 10-pin header still fits in pins
  1-10.
- D8: optional footprint for a 5.1V zener (DO-35, upright) in parallel with U5, as an
  alternative to the LM4040LP-5 for the -5V reference. Fit U5 or D8, not both.

### Changed

- Arduino Nano VIN (A1 pin 30) is now fed from +12V (from the U4 input pin) instead of
  the +5V rail, so the v0.042 VIN bodge is no longer needed. U4 still supplies the
  module's +5V rail by default; the Nano's own 5V output (pin 27) can be connected to
  it with JP5.
- LED resistors R25-R28 changed from 100r to 4.7k (the LEDs were too bright).
- U4 (L7805, TO-220) now uses a horizontal tab-down footprint: it lies flat on the back
  PCB with its M3 tab hole, and the GND pour under the tab (with stitching vias) acts as
  the heatsink. Only GND copper is under the tab on the top layer. C12 moved up slightly
  to make room. The whole v0.042 module (Nano included) drew 28-38mA from +12V, so U4
  dissipates at most (12-5)V x 38mA = ~0.27W and a separate heatsink shouldn't be needed.
- Back PCB outline moved 1mm to the right (as seen from the front panel). All parts and
  inter-board headers stay put, so the back PCB's left edge is now flush with the jack
  PCB's (previously it overhung by ~0.9mm).
- MIDI IN pull-up R47 changed from 220R to 1k (220R would sink ~23mA through the
  HCPL-263x output, which is specified at 13mA). D7 (1N4148) is now only fitted for the
  6N138 build, R46 (4.7k) uses a 5.08mm-pitch footprint, and the area around U8 on the
  jack PCB was re-placed and re-routed.
- D5 moved left and R29 now stands upright (2.54mm pitch) to make room for the 16-pin
  power header; the power tracks around J12 were re-routed.
- PCB layout revisions.
- Version on the schematic title block and PCB silkscreen updated to v0.5.0.

### Fixed

- The back PCB's 2-pin MIDI header existed only on the PCB and shared the reference J4
  with the jack PCB's MIDI-IN/RND-OUT jumper header. It is now J9 and is in the
  schematic.
- The front silkscreen labels on that header were swapped: pin 1 is D0/RX (MIDI IN) and
  pin 2 is D1/TX (MIDI OUT).

## [0.042] - 2024-12-31

### Added

- Initial release.

[0.5.0]: https://github.com/semi-sensible-synth/triggerspace/compare/v0.042...main
[0.042]: https://github.com/semi-sensible-synth/triggerspace/releases/tag/v0.042

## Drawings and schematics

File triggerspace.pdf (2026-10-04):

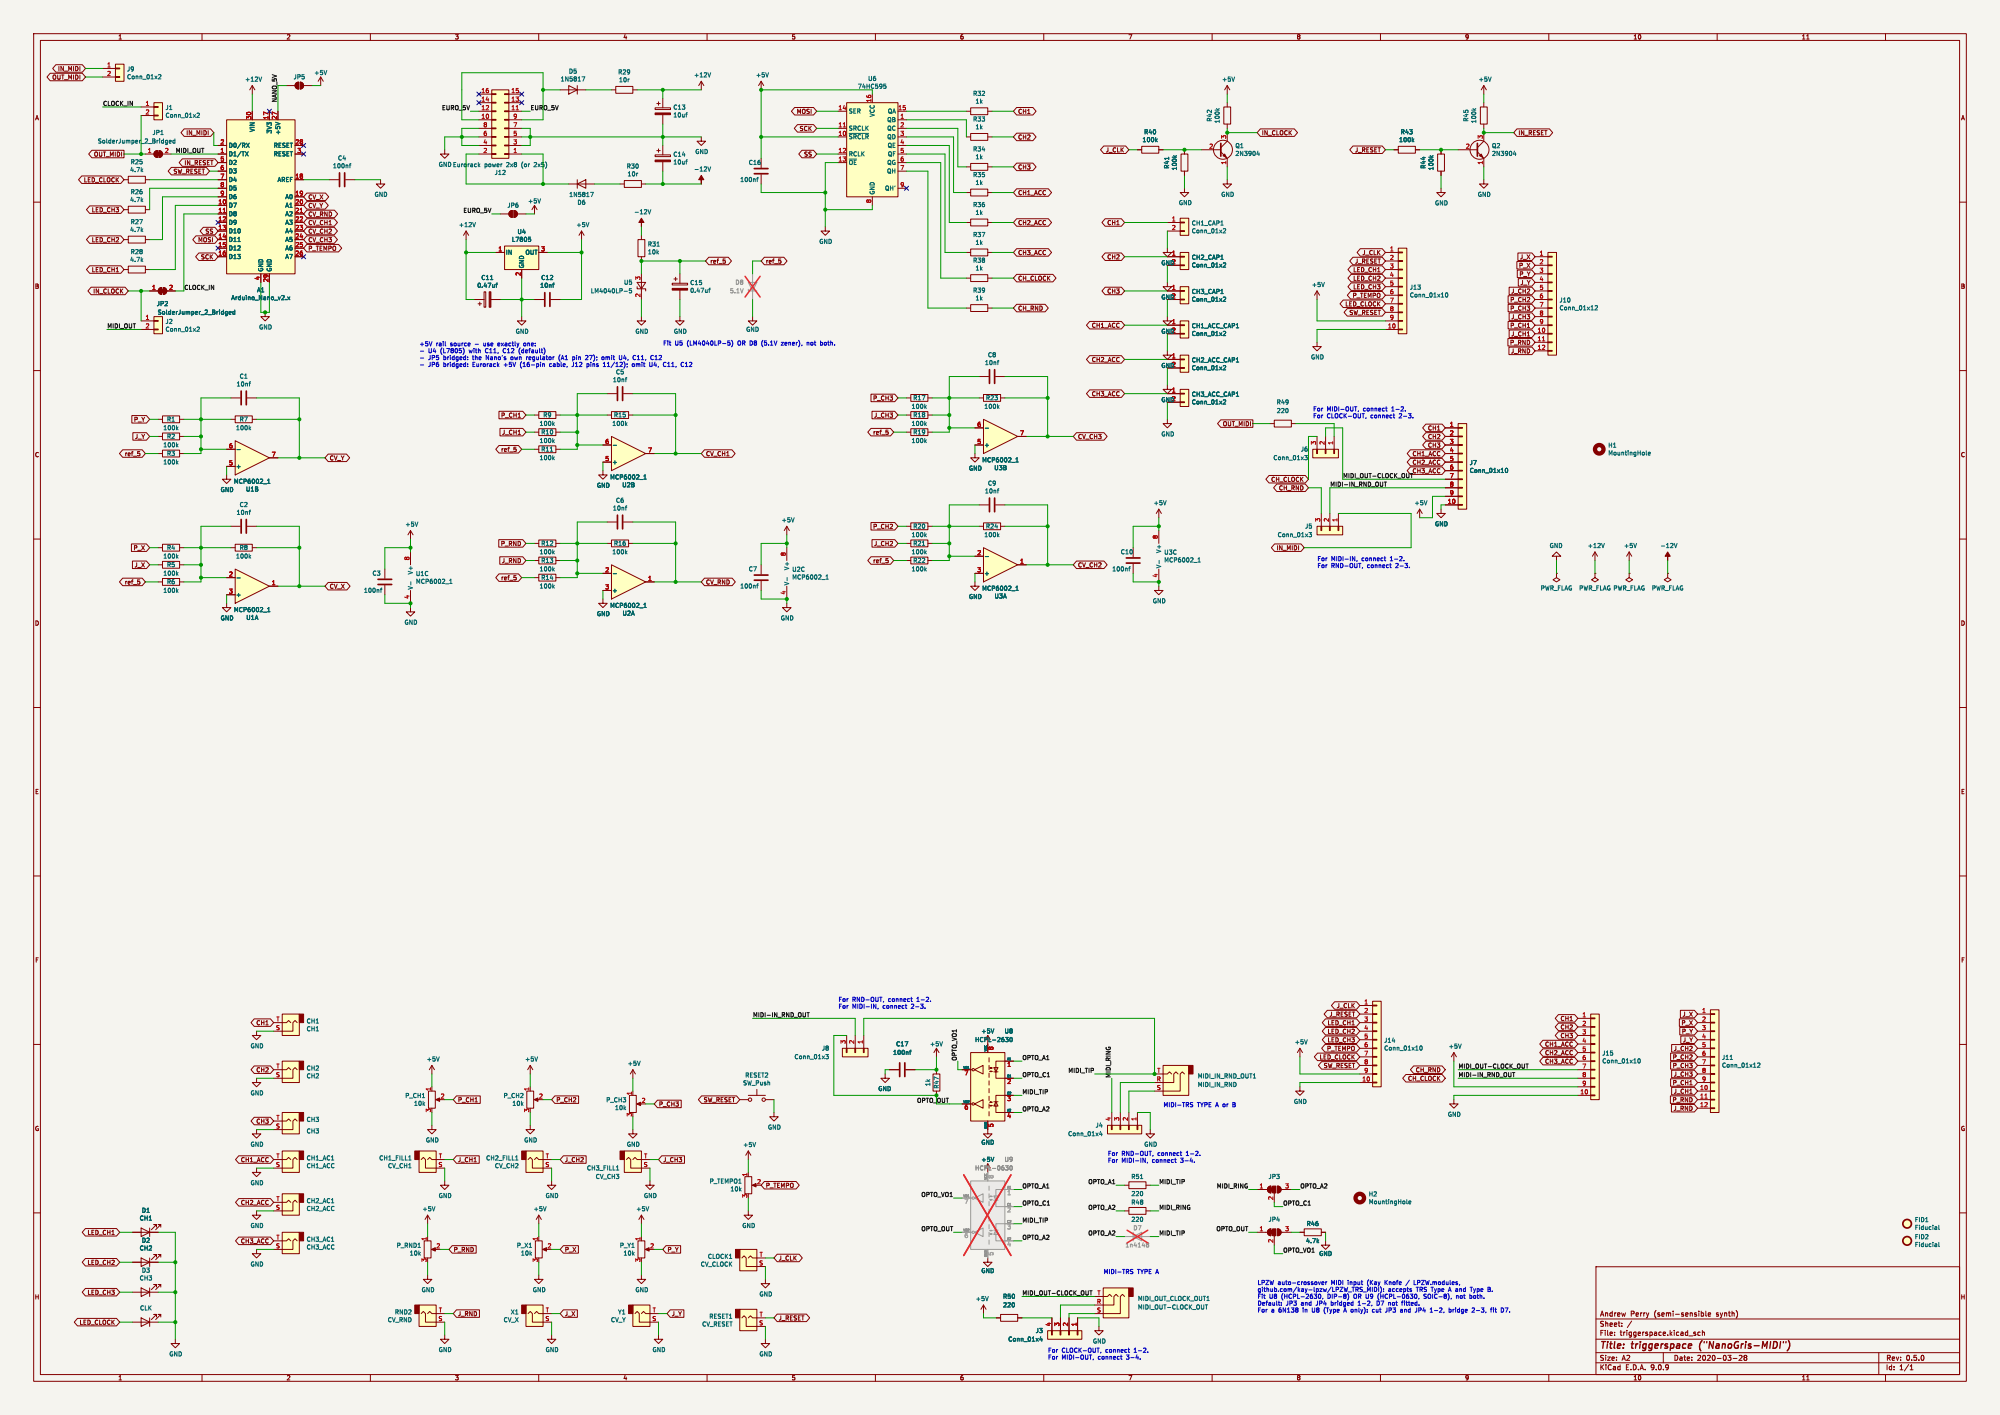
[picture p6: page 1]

4 3V3 17 GND 29 +5V 27 RESET 28 RESET 3 AREF 18 A0 19 A1 20 A2 21 A3 22 A4 23 A5 24 A6 25 A7 26 A1 Arduino_Nano_v2.x GND

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

MIDI-TRS TYPE A or B

For CLOCK-OUT, connect 1-2. For MIDI-OUT, connect 3-4.

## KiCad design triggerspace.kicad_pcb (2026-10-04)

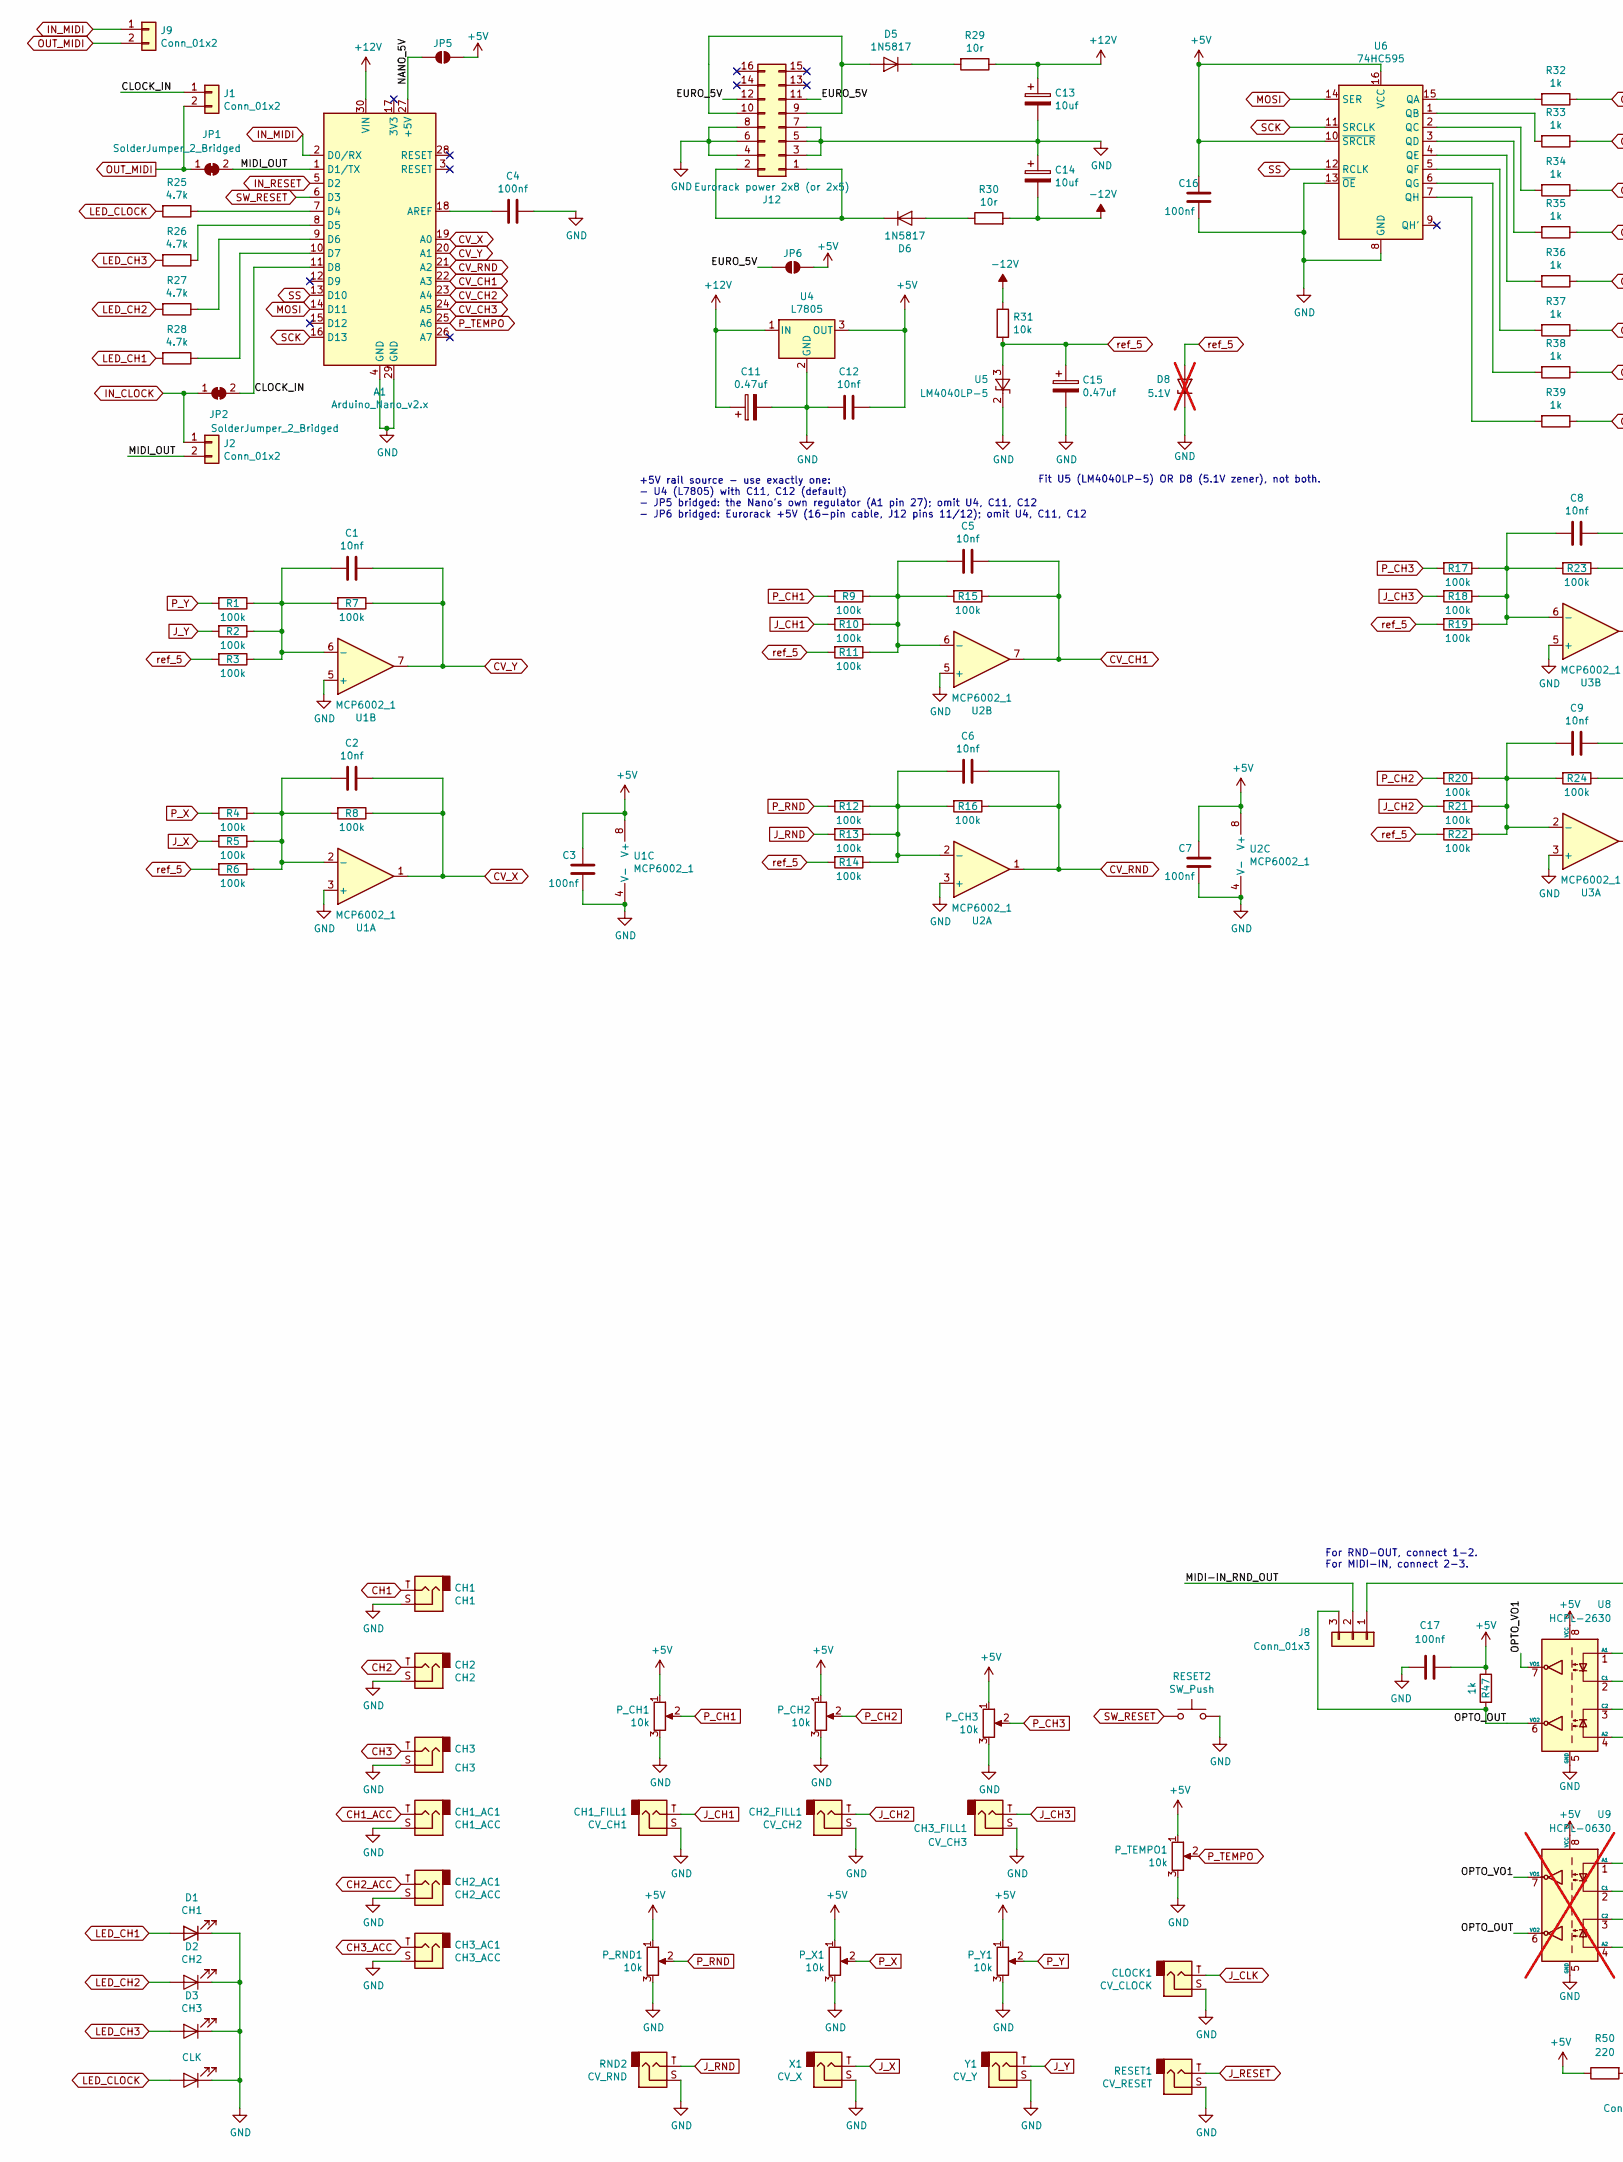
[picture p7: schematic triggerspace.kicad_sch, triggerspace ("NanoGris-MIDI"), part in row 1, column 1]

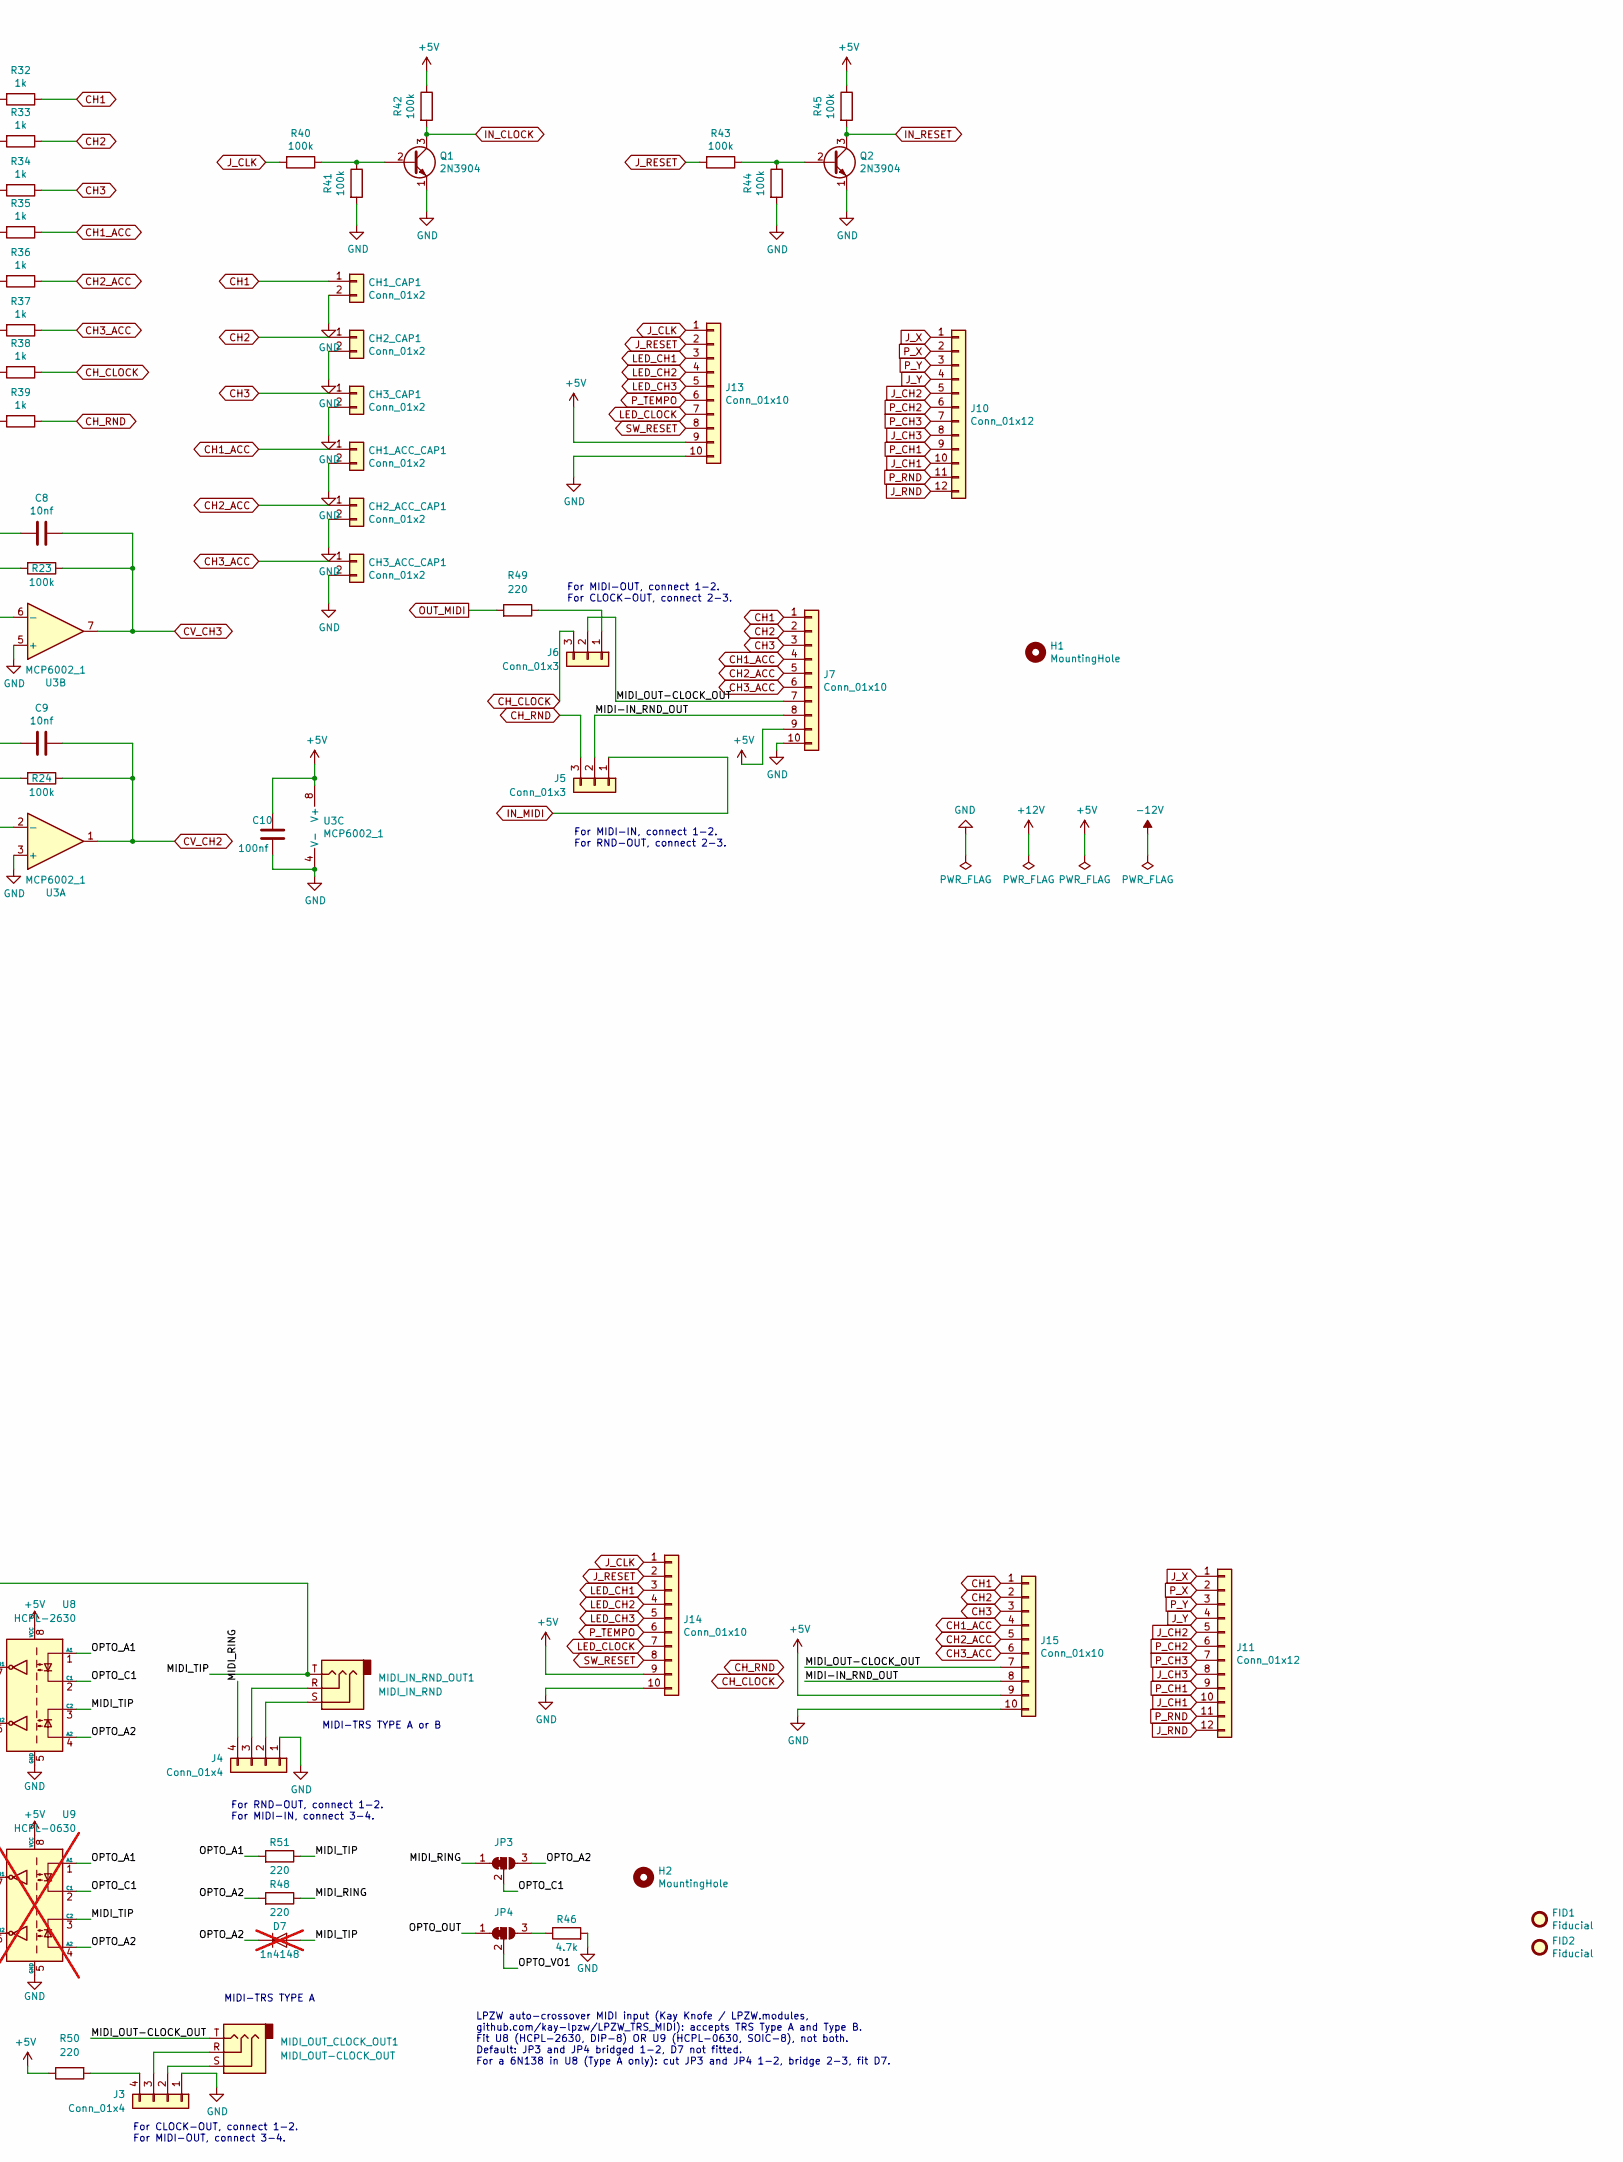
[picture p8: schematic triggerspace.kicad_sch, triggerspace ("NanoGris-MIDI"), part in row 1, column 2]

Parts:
A1: Arduino_Nano_v2.x; Arduino_Nano
C1, C2, C5, C6, C8, C9, C12: 10nf; C_Disc_D5.0mm_W2.5mm_P2.50mm
C3, C4, C7, C10, C16, C17: 100nf; C_Disc_D5.0mm_W2.5mm_P2.50mm
C11, C15: 0.47uf; CP_Radial_D5.0mm_P2.50mm
C13, C14: 10uf; CP_Radial_D5.0mm_P2.50mm
CH1: CH1; Jack_3.5mm_QingPu_WQP-PJ398SM_Vertical_CircularHoles
CH1_AC1: CH1_ACC; Jack_3.5mm_QingPu_WQP-PJ398SM_Vertical_CircularHoles
CH1_ACC_CAP1, CH1_CAP1, CH2_ACC_CAP1, CH2_CAP1, CH3_ACC_CAP1, CH3_CAP1: Conn_01x2; PinSocket_1x02_P2.54mm_Vertical
CH1_FILL1: CV_CH1; Jack_3.5mm_QingPu_WQP-PJ398SM_Vertical_CircularHoles
CH2: CH2; Jack_3.5mm_QingPu_WQP-PJ398SM_Vertical_CircularHoles
CH2_AC1: CH2_ACC; Jack_3.5mm_QingPu_WQP-PJ398SM_Vertical_CircularHoles
CH2_FILL1: CV_CH2; Jack_3.5mm_QingPu_WQP-PJ398SM_Vertical_CircularHoles
CH3: CH3; Jack_3.5mm_QingPu_WQP-PJ398SM_Vertical_CircularHoles
CH3_AC1: CH3_ACC; Jack_3.5mm_QingPu_WQP-PJ398SM_Vertical_CircularHoles
CH3_FILL1: CV_CH3; Jack_3.5mm_QingPu_WQP-PJ398SM_Vertical_CircularHoles
CLOCK1: CV_CLOCK; Jack_3.5mm_QingPu_WQP-PJ398SM_Vertical_CircularHoles
D1: CH1; LED_D3.0mm
D2: CH2; LED_D3.0mm
D3: CH3; LED_D3.0mm
D4: CLK; LED_D3.0mm
D5, D6: 1N5817; D_DO-34_SOD68_P7.62mm_Horizontal
D7: 1n4148; D_DO-34_SOD68_P7.62mm_Horizontal; not fitted
D8: 5.1V; D_DO-35_SOD27_P2.54mm_Vertical_KathodeUp; not fitted
FID1: Fiducial; OSHW-Logo2_7.3x6mm_SilkScreen
FID2: Fiducial; OSHW-Logo2_14.6x12mm_SilkScreen
H1, H2: MountingHole; MountingHole_3.2mm_M3
J1, J2, J9: Conn_01x2; PinSocket_1x02_P2.54mm_Vertical
J3, J4: Conn_01x4; PinHeader_1x04_P2.54mm_Vertical
J5, J6, J8: Conn_01x3; PinHeader_1x03_P2.54mm_Vertical
J7, J13: Conn_01x10; PinSocket_1x10_P2.54mm_Vertical
J10: Conn_01x12; PinSocket_1x12_P2.54mm_Vertical
J11: Conn_01x12; PinHeader_1x12_P2.54mm_Vertical
J12: Eurorack power 2x8 (or 2x5); IDC-Header_2x08_P2.54mm_Vertical
J14, J15: Conn_01x10; PinHeader_1x10_P2.54mm_Vertical
JP1, JP2: SolderJumper_2_Bridged; SolderJumper-2_P1.3mm_Bridged_RoundedPad1.0x1.5mm
JP3, JP4: SolderJumper_3_Bridged12; SolderJumper-3_P1.3mm_Bridged12_RoundedPad1.0x1.5mm_NumberL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
JP5, JP6: SolderJumper_2_Open; SolderJumper-2_P1.3mm_Open_RoundedPad1.0x1.5mm
MIDI_IN_RND_OUT1: MIDI_IN_RND; Jack_3.5mm_QingPu_WQP-PJ398SM_Vertical_CircularHoles
MIDI_OUT_CLOCK_OUT1: MIDI_OUT-CLOCK_OUT; Jack_3.5mm_QingPu_WQP-PJ398SM_Vertical_CircularHoles
P_CH1, P_CH2, P_CH3: 10k; Potentiometer_Alps_RK09K_Single_Vertical_round
P_RND1: 10k; Potentiometer_Alps_RK09K_Single_Vertical_round
P_TEMPO1: 10k; Potentiometer_Alps_RK09K_Single_Vertical_round
P_X1: 10k; Potentiometer_Alps_RK09K_Single_Vertical_round
P_Y1: 10k; Potentiometer_Alps_RK09K_Single_Vertical_round
Q1, Q2: 2N3904; TO-92_Wide
R1, R2, R3, R4, R5, R6, R7, R8, R9, R10, R11, R12, R13, R14, R15, R16, R17, R18, R19, R20, R21, R22, R23, R24, R40, R41, R42, R43, R44, R45: 100k; R_Axial_DIN0204_L3.6mm_D1.6mm_P7.62mm_Horizontal
R25, R26, R27, R28: 4.7k; R_Axial_DIN0207_L6.3mm_D2.5mm_P7.62mm_Horizontal
R29: 10r; R_Axial_DIN0204_L3.6mm_D1.6mm_P2.54mm_Vertical
R30: 10r; R_Axial_DIN0204_L3.6mm_D1.6mm_P7.62mm_Horizontal
R31: 10k; R_Axial_DIN0204_L3.6mm_D1.6mm_P7.62mm_Horizontal
R32, R33, R34, R35, R36, R37, R38, R39, R47: 1k; R_Axial_DIN0204_L3.6mm_D1.6mm_P7.62mm_Horizontal
R46: 4.7k; R_Axial_DIN0204_L3.6mm_D1.6mm_P5.08mm_Horizontal
R48, R49, R50, R51: 220; R_Axial_DIN0204_L3.6mm_D1.6mm_P7.62mm_Horizontal
RESET1: CV_RESET; Jack_3.5mm_QingPu_WQP-PJ398SM_Vertical_CircularHoles
RESET2: SW_Push; SW_PUSH_6mm
RND2: CV_RND; Jack_3.5mm_QingPu_WQP-PJ398SM_Vertical_CircularHoles
U1, U2, U3: MCP6002_1; DIP-8_W7.62mm
U4: L7805; TO-220-3_Horizontal_TabDown
U5: LM4040LP-5; TO-92_Wide
U6: 74HC595; DIP-16_W7.62mm
U8: HCPL-2630; DIP-8_W7.62mm_Socket_LongPads
U9: HCPL-0630; SOIC-8_3.9x4.9mm_P1.27mm; not fitted
X1: CV_X; Jack_3.5mm_QingPu_WQP-PJ398SM_Vertical_CircularHoles
Y1: CV_Y; Jack_3.5mm_QingPu_WQP-PJ398SM_Vertical_CircularHoles

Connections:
+5V: C3.1, C7.1, C10.1, C12.1, C16.1, C17.1, J7.9, J13.9, J14.9, J15.9, JP5.2 (B), JP6.2 (B), P_CH1.1, P_CH2.1, P_CH3.1, P_RND1.1, P_TEMPO1.1, P_X1.1, P_Y1.1, R42.1, R45.1, R47.1, R50.1, U1.8 (V+), U2.8 (V+), U3.8 (V+), U4.3 (OUT), U6.10 (~SRCLR), U6.16 (VCC), U8.8 (VCC), U9.8 (VCC)
+12V: A1.30 (VIN), C11.1, C13.1, R29.1, U4.1 (IN)
-12V: C14.2, R30.2, R31.1
/CLOCK_IN: A1.11 (D8), J1.1, JP2.2 (B)
/EURO_5V: J12.11, J12.12, JP6.1 (A)
/MIDI-IN_RND_OUT: J5.2, J7.8, J8.2, J15.8
/MIDI_OUT: A1.1 (D1/TX), J2.2, JP1.2 (B)
/MIDI_OUT-CLOCK_OUT: J6.2, J7.7, J15.7, MIDI_OUT_CLOCK_OUT1.T
/MIDI_RING: J4.4, JP3.1 (A), R48.1
/MIDI_TIP: D7.2 (A), J8.1, MIDI_IN_RND_OUT1.T, R51.1, U8.3 (C2), U9.3 (C2)
/NANO_5V: A1.27 (+5V), JP5.1 (A)
/OPTO_A1: R51.2, U8.1 (NC), U9.1 (A1)
/OPTO_A2: D7.1 (K), JP3.3 (B), R48.2, U8.4 (NC), U9.4 (A2)
/OPTO_C1: JP3.2 (C), U8.2 (C1), U9.2 (C1)
/OPTO_OUT: J8.3, JP4.1 (A), R47.2, U8.6 (VO2), U9.6 (VO2)
/OPTO_VO1: JP4.2 (C), U8.7 (VO1), U9.7 (VO1)
CH1: CH1.T, CH1_CAP1.1, J7.1, J15.1, R32.1
CH1_ACC: CH1_AC1.T, CH1_ACC_CAP1.1, J7.4, J15.4, R35.1
CH2: CH2.T, CH2_CAP1.1, J7.2, J15.2, R33.1
CH2_ACC: CH2_AC1.T, CH2_ACC_CAP1.1, J7.5, J15.5, R36.1
CH3: CH3.T, CH3_CAP1.1, J7.3, J15.3, R34.1
CH3_ACC: CH3_AC1.T, CH3_ACC_CAP1.1, J7.6, J15.6, R37.1
CH_CLOCK: J6.3, R38.1
CH_RND: J5.3, R39.1
CV_CH1: A1.22 (A3), C5.1, R15.1, U2.7
CV_CH2: A1.23 (A4), C9.1, R24.1, U3.1
CV_CH3: A1.24 (A5), C8.1, R23.1, U3.7
CV_RND: A1.21 (A2), C6.1, R16.1, U2.1
CV_X: A1.19 (A0), C2.1, R8.1, U1.1
CV_Y: A1.20 (A1), C1.1, R7.1, U1.7
GND: A1.4 (GND), A1.29 (GND), C3.2, C4.1, C7.2, C10.2, C11.2, C12.2, C13.2, C14.1, C15.2, C16.2, C17.2, CH1.S, CH1_AC1.S, CH1_ACC_CAP1.2, CH1_CAP1.2, CH1_FILL1.S, CH2.S, CH2_AC1.S, CH2_ACC_CAP1.2, CH2_CAP1.2, CH2_FILL1.S, CH3.S, CH3_AC1.S, CH3_ACC_CAP1.2, CH3_CAP1.2, CH3_FILL1.S, CLOCK1.S, D1.1 (K), D2.1 (K), D3.1 (K), D4.1 (K), D8.1 (K), J3.1, J4.1, J7.10, J12.3, J12.4, J12.5, J12.6, J12.7, J12.8, J13.10, J14.10, J15.10, P_CH1.3, P_CH2.3, P_CH3.3, P_RND1.3, P_TEMPO1.3, P_X1.3, P_Y1.3, Q1.1 (E), Q2.1 (E), R41.2, R44.2, R46.2, RESET1.S, RESET2.2, RND2.S, U1.3 (+), U1.4 (V-), U1.5 (+), U2.3 (+), U2.4 (V-), U2.5 (+), U3.3 (+), U3.4 (V-), U3.5 (+), U4.2 (GND), U5.2 (K), U6.8 (GND), U6.13 (~OE), U8.5 (GND), U9.5 (GND), X1.S, Y1.S
IN_CLOCK: J2.1, JP2.1 (A), Q1.3 (C), R42.2
IN_MIDI: A1.2 (D0/RX), J5.1, J9.1
IN_RESET: A1.5 (D2), Q2.3 (C), R45.2
J_CH1: CH1_FILL1.T, J10.10, J11.10, R10.2
J_CH2: CH2_FILL1.T, J10.5, J11.5, R21.2
J_CH3: CH3_FILL1.T, J10.8, J11.8, R18.2
J_CLK: CLOCK1.T, J13.1, J14.1, R40.2
J_RESET: J13.2, J14.2, R43.2, RESET1.T
J_RND: J10.12, J11.12, R13.2, RND2.T
J_X: J10.1, J11.1, R5.2, X1.T
J_Y: J10.4, J11.4, R2.2, Y1.T
LED_CH1: D1.2 (A), J13.3, J14.3, R28.2
LED_CH2: D2.2 (A), J13.4, J14.4, R27.2
LED_CH3: D3.2 (A), J13.5, J14.5, R26.2
LED_CLOCK: D4.2 (A), J13.7, J14.7, R25.2
MOSI: A1.14 (D11), U6.14 (SER)
unnamed: A1.18 (AREF), C4.2
unnamed: A1.7 (D4), R25.1
unnamed: A1.8 (D5), R26.1
unnamed: A1.9 (D6), R27.1
unnamed: A1.10 (D7), R28.1
unnamed: D5.2 (A), J12.9, J12.10
unnamed: D5.1 (K), R29.2
unnamed: D6.2 (A), R30.1
unnamed: D6.1 (K), J12.1, J12.2
unnamed: J3.2, MIDI_OUT_CLOCK_OUT1.S
unnamed: J3.3, MIDI_OUT_CLOCK_OUT1.R
unnamed: J3.4, R50.2
unnamed: J4.2, MIDI_IN_RND_OUT1.S
unnamed: J4.3, MIDI_IN_RND_OUT1.R
unnamed: J6.1, R49.1
unnamed: JP4.3 (B), R46.1
unnamed: Q1.2 (B), R40.1, R41.1
unnamed: Q2.2 (B), R43.1, R44.1
unnamed: C2.2, R4.1, R5.1, R6.1, R8.2, U1.2 (-)
unnamed: C1.2, R1.1, R2.1, R3.1, R7.2, U1.6 (-)
unnamed: C6.2, R12.1, R13.1, R14.1, R16.2, U2.2 (-)
unnamed: C5.2, R9.1, R10.1, R11.1, R15.2, U2.6 (-)
unnamed: C9.2, R20.1, R21.1, R22.1, R24.2, U3.2 (-)
unnamed: C8.2, R17.1, R18.1, R19.1, R23.2, U3.6 (-)
unnamed: R32.2, U6.15 (QA)
unnamed: R33.2, U6.1 (QB)
unnamed: R34.2, U6.2 (QC)
unnamed: R35.2, U6.3 (QD)
unnamed: R36.2, U6.4 (QE)
unnamed: R37.2, U6.5 (QF)
unnamed: R38.2, U6.6 (QG)
unnamed: R39.2, U6.7 (QH)
OUT_MIDI: J1.2, J9.2, JP1.1 (A), R49.2
P_CH1: J10.9, J11.9, P_CH1.2, R9.2
P_CH2: J10.6, J11.6, P_CH2.2, R20.2
P_CH3: J10.7, J11.7, P_CH3.2, R17.2
P_RND: J10.11, J11.11, P_RND1.2, R12.2
P_TEMPO: A1.25 (A6), J13.6, J14.6, P_TEMPO1.2
P_X: J10.2, J11.2, P_X1.2, R4.2
P_Y: J10.3, J11.3, P_Y1.2, R1.2
SCK: A1.16 (D13), U6.11 (SRCLK)
SS: A1.13 (D10), U6.12 (RCLK)
SW_RESET: A1.6 (D3), J13.8, J14.8, RESET2.1
ref_5: C15.1, D8.2 (A), R3.2, R6.2, R11.2, R14.2, R19.2, R22.2, R31.2, U5.3 (A)

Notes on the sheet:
For MIDI-OUT, connect 1-2. For CLOCK-OUT, connect 2-3.
For RND-OUT, connect 1-2. For MIDI-IN, connect 3-4.
For MIDI-IN, connect 1-2. For RND-OUT, connect 2-3.
For CLOCK-OUT, connect 1-2. For MIDI-OUT, connect 3-4.
MIDI-TRS TYPE A
For RND-OUT, connect 1-2. For MIDI-IN, connect 2-3.
MIDI-TRS TYPE A or B
LPZW auto-crossover MIDI input (Kay Knofe / LPZW.modules, github.com/kay-lpzw/LPZW_TRS_MIDI): accepts TRS Type A and Type B. Fit U8 (HCPL-2630, DIP-8) OR U9 (HCPL-0630, SOIC-8), not both. Default: JP3 and JP4 bridged 1-2, D7 not fitted. For a 6N138 in U8 (Type A only): cut JP3 and JP4 1-2, bridge 2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
Fit U5 (LM4040LP-5) OR D8 (5.1V zener), not both.
+5V rail source - use exactly one: - U4 (L7805) with C11, C12 (default) - JP5 bridged: the Nano's own regulator (A1 pin 27); omit U4, C11, C12 - JP6 bridged: Eurorack +5V (16-pin cable, J12 pins 11/12); omit U4, C11, C12

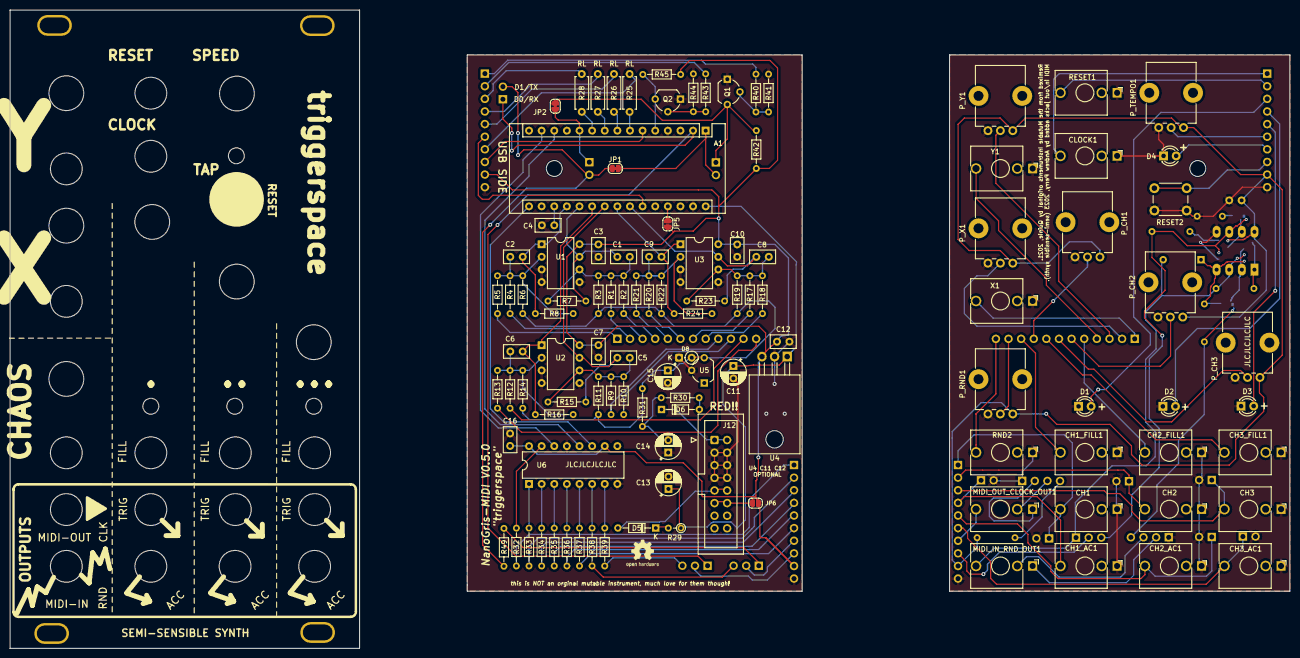
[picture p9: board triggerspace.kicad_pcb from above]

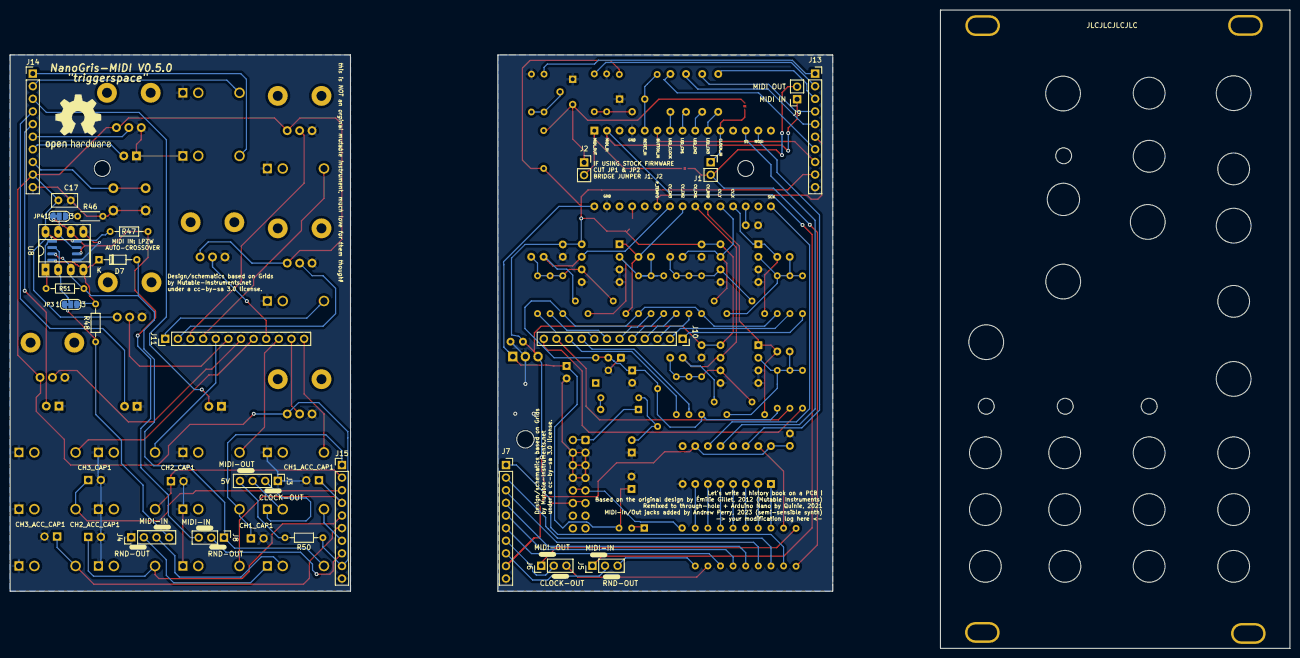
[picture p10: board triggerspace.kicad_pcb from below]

Board: 2 copper layers, 257.6 x 128.5 mm, 170 parts (32 on the bottom side), 91 nets.

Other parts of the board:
H1#2, H2#2, H3, H4, H5, H6, H7, H8, H9, H10, H11, H12, H13, H14, H15, H16, H17: MountingHole; MountingHole_6mm
H18, H19, H20, H21: MountingHole; MountingHole_3mm
H22, H23, H24, H25, H26, H27, H28: MountingHole; MountingHole_8.4mm_M8

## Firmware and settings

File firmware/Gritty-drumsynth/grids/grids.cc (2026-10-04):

// Copyright 2012 Emilie Gillet.
//
// Author: Emilie Gillet (emilie.o.gillet@gmail.com)
//
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
// Modified by Sonic Insurgence, June 2021 — improved MIDI implementation.
// Modified by Andrew Perry (semi-sensible synth), 2024 — MIDI out on channel 10.
//
// Gritty-drumsynth, 2026
// ----------------------
// This fork keeps the Grids topographic sequencer, clock and MIDI intact, but
// replaces the raw voltage-trigger outputs with three internally SYNTHESISED
// 808/909-style drum voices rendered as 1-bit PDM (delta-sigma) on the existing
// BD/SD/HH jacks. A synthesised low sine is hugely oversampled by the modulator,
// so the kick comes out clean instead of an overdriven 1-bit sample.
//
// Two ISRs, on two timers:
//   * TIMER2 (~8 kHz, unchanged): the Grids control tick — clock, sequencer,
//     MIDI-in, tap button, LEDs. It no longer writes the 595; a sequencer
//     trigger now fires a voice envelope (the single integration point in
//     UpdateShiftRegister()).
//   * TIMER1 (Fs = 31.25 kHz): the audio tick — runs one 1-bit sigma-delta
//     modulator per drum jack on the currently-held voice sample and clocks the
//     packed byte to the 74HC595. It is short and constant-time; because the
//     TIMER2 control ISR is ISR_NOBLOCK, the audio ISR pre-empts it and keeps a
//     steady PDM carrier.
// The heavy per-voice synthesis runs in the main loop, paced by the audio ISR to
// a fixed synth rate (Fs / kSynthDecimation ~= 7.8 kHz); the ISR just holds and
// re-modulates the last sample (zero-order hold). This amortises the DSP math
// out from under the hard-real-time 1-bit output loop.

#include <avr/eeprom.h>
#include <avr/pgmspace.h>

#include "avrlib/adc.h"
#include "avrlib/boot.h"
#include "avrlib/op.h"
#include "avrlib/watchdog_timer.h"

#include "grids/clock.h"
#include "grids/hardware_config.h"
#include "grids/pattern_generator.h"
#include "grids/midi.h"

using namespace avrlib;
using namespace grids;

Leds leds;
ResetInput reset_input;
ButtonInput button_input;
ClockInput clock_input;

AdcInputScanner adc;
ShiftRegister shift_register;
MidiIO midi;

// ===========================================================================
// Drum synthesis engine
// ===========================================================================

// Diagnostic: force a continuous ~220 Hz tone on all three drum jacks, ignoring
// the sequencer / triggers / mute. Use it to verify the audio ISR + PDM + output
// path independently of the trigger logic. Comment out for the real drum engine.
//#define DRUMSYNTH_TEST_TONE

// --- Sample clocks --------------------------------------------------------
// Audio (PDM) ISR on Timer1, CTC, prescaler /1: Fs = F_CPU / (OCR1A + 1).
// 16 MHz / 512 = 31.25 kHz.  Kept moderate so the full Grids control ISR (Timer2,
// ~8 kHz) plus the main-loop synth all fit the 16 MHz budget with headroom; the
// lower carrier also reconstructs better through the trigger output stage.
// Synthesis is decimated by kSynthDecimation -> ~7.8 kHz synth rate (plenty for
// a 55 Hz kick and a few-kHz hat).
static const uint32_t kAudioRate  = 31250UL;
static const uint16_t kOcr1a      = (F_CPU / kAudioRate) - 1;   // = 511 @ 16 MHz
static const uint8_t  kSynthDecimation = 4;                     // -> ~7812 Hz
static const uint32_t kSynthRate  = kAudioRate / kSynthDecimation;

// Convert a frequency (Hz) to a 16-bit phase increment at the synth rate.
// inc = f * 2^16 / Fs_synth.  (Compile-time for the voice defaults.)
#define HZ_TO_INC(hz)  ((uint16_t)(((uint32_t)(hz) * 65536UL) / kSynthRate))

// --- Signed sine, one period, 8-bit (-127..127), 256 entries --------------
static const int8_t kSine[256] PROGMEM = {
     0,    3,    6,    9,   12,   16,   19,   22,
    25,   28,   31,   34,   37,   40,   43,   46,
    49,   51,   54,   57,   60,   63,   65,   68,
    71,   73,   76,   78,   81,   83,   85,   88,
    90,   92,   94,   96,   98,  100,  102,  104,
   106,  107,  109,  111,  112,  113,  115,  116,
   117,  118,  120,  121,  122,  122,  123,  124,
   125,  125,  126,  126,  126,  127,  127,  127,
   127,  127,  127,  127,  126,  126,  126,  125,
   125,  124,  123,  122,  122,  121,  120,  118,
   117,  116,  115,  113,  112,  111,  109,  107,
   106,  104,  102,  100,   98,   96,   94,   92,
    90,   88,   85,   83,   81,   78,   76,   73,
    71,   68,   65,   63,   60,   57,   54,   51,
    49,   46,   43,   40,   37,   34,   31,   28,
    25,   22,   19,   16,   12,    9,    6,    3,
     0,   -3,   -6,   -9,  -12,  -16,  -19,  -22,
   -25,  -28,  -31,  -34,  -37,  -40,  -43,  -46,
   -49,  -51,  -54,  -57,  -60,  -63,  -65,  -68,
   -71,  -73,  -76,  -78,  -81,  -83,  -85,  -88,
   -90,  -92,  -94,  -96,  -98, -100, -102, -104,
  -106, -107, -109, -111, -112, -113, -115, -116,
  -117, -118, -120, -121, -122, -122, -123, -124,
  -125, -125, -126, -126, -126, -127, -127, -127,
  -127, -127, -127, -127, -126, -126, -126, -125,
  -125, -124, -123, -122, -122, -121, -120, -118,
  -117, -116, -115, -113, -112, -111, -109, -107,
  -106, -104, -102, -100,  -98,  -96,  -94,  -92,
   -90,  -88,  -85,  -83,  -81,  -78,  -76,  -73,
   -71,  -68,  -65,  -63,  -60,  -57,  -54,  -51,
   -49,  -46,  -43,  -40,  -37,  -34,  -31,  -28,
   -25,  -22,  -19,  -16,  -12,   -9,   -6,   -3,
};

static inline int8_t Sine(uint8_t phase_hi)
{
  return (int8_t)pgm_read_byte(&kSine[phase_hi]);
}

// --- Voice parameters (RAM; defaults here, live-tunable via MIDI CC) -------
// "Decay" values are the exponential retain-per-synth-tick coefficient (Q8):
// higher = longer tail.  amp/pitch envelopes are 16-bit, x = U16U16MulShift16(x,d).
struct VoiceParams {
  uint16_t base_inc;     // steady-state pitch (phase increment @ synth rate)
  uint16_t pitch_mod0;   // initial pitch-envelope excursion (added to base_inc)
  uint16_t pitch_decay;  // pitch-env retain/tick, 16-bit (65536 = no decay)
  uint16_t amp_decay;    // amp-env retain/tick, 16-bit
  uint16_t noise_decay;  // 2nd (noise) amp-env retain/tick, 16-bit (snare/hat)
  uint8_t  tone_level;   // tonal component level 0..255
  uint8_t  noise_level;  // noise component level 0..255
};

// Kick, snare, hat defaults. Decays are 16-bit exponential retain-per-tick at the
// ~7.8 kHz synth rate: tau_ms ~= -1000 / (ln(d/65536) * 7812). e.g. 65480 ~= 150 ms,
// 65327 ~= 40 ms. (8-bit decays topped out near 16 ms -> everything was a click.)
static VoiceParams params[3] = {
  // base_inc            pitch_mod0                    pDecay aDecay nDecay tone noise
  { HZ_TO_INC(55),  HZ_TO_INC(320) - HZ_TO_INC(55),   65120, 65480,     0, 255,   0 }, // BD kick
  { HZ_TO_INC(190), HZ_TO_INC(120),                   65535, 65380, 65460, 150, 210 }, // SD snare
  { HZ_TO_INC(1800), 0,                               65535, 65535, 65300,   0, 255 }, // HH hat (tone=metal amount)
};

// --- EEPROM persistence for the voice params -------------------------------
// pattern_generator owns EEPROM bytes 0..1; the voice params live well clear of
// it. A magic/version byte guards the block so a fresh chip (or a struct-layout
// change) falls back to the compiled defaults above instead of loading garbage.
static const uint16_t kVoiceEepromAddr  = 16;
static const uint8_t  kVoiceEepromMagic = 0xD4;  // bump if VoiceParams changes

static void SaveVoiceParams()
{
  eeprom_write_block(params, (void*)(kVoiceEepromAddr + 1), sizeof(params));
  eeprom_write_byte((uint8_t*)kVoiceEepromAddr, kVoiceEepromMagic);
}

static void LoadVoiceParams()
{
  if (eeprom_read_byte((uint8_t*)kVoiceEepromAddr) == kVoiceEepromMagic)
  {
    eeprom_read_block(params, (const void*)(kVoiceEepromAddr + 1), sizeof(params));
  }
}

// --- Per-voice runtime state ----------------------------------------------
static uint16_t v_phase[3];       // oscillator phase accumulator
static uint16_t v_pitch_mod[3];   // decaying pitch excursion
static uint16_t v_amp[3];         // tonal amplitude envelope (0..0xffff)
static uint16_t v_namp[3];        // noise amplitude envelope (0..0xffff)
static uint16_t lfsr = 0xACE1u;   // shared noise generator
static int8_t   noise_prev;       // for the 1st-difference high-pass

// Per-hit copies of the pitch / decay params, latched at TriggerVoice() so the
// performance-mode Randomness knob can jitter them per hit without touching the
// stored params[] (see ParamJitter/JitterDecay).
static uint16_t v_base_inc[3];    // this hit's pitch (params.base_inc +/- jitter)
static uint16_t v_amp_decay[3];   // this hit's amp-env decay
static uint16_t v_namp_decay[3];  // this hit's noise-env decay

// The current instantaneous voice output (signed, ~-128..127). Written by the
// main-loop synth, read by the audio ISR — single bytes, atomic on AVR.
static volatile int8_t voice_sample[3] = { 0, 0, 0 };
// Accent-jack gate bits (0x08 BD, 0x10 SD, 0x20 HH), set while an accented hit
// is sounding.  ORed into the 595 byte by the audio ISR.
static volatile uint8_t accent_bits = 0;

// Trigger latches: control ISR / MIDI-in raise a bit per voice, synth consumes.
static volatile uint8_t v_trigger = 0;   // bit i = fire voice i
static volatile uint8_t v_accent  = 0;   // bit i = that hit is accented

// Synth pacing: audio ISR bumps this once per kSynthDecimation ticks; the main
// loop renders that many samples. Keeps the heavy DSP out of the ISR.
static volatile uint8_t synth_pending = 0;

static inline uint8_t NextNoise()
{
  // 16-bit Galois LFSR, taps 0xB400.
  uint8_t lsb = lfsr & 1u;
  lfsr >>= 1;
  if (lsb) lfsr ^= 0xB400u;
  return (uint8_t)(lfsr >> 8);
}

// Per-hit parameter jitter driven by the performance-mode Randomness/chaos knob
// (0..255). Returns a signed perturbation of `base`, scaled by chaos and by
// max_q10 = the maximum |delta|/base at full chaos, in 1/1024 units (20 ~= 2%,
// 205 ~= 20%). chaos=0 => no variation. Shared noise LFSR gives the sign/size.
static int16_t ParamJitter(uint16_t base, uint8_t chaos, uint8_t max_q10)
{
  int8_t r = (int8_t)NextNoise();                 // -128..127
  int16_t s = ((int16_t)chaos * r) >> 8;          // ~ -128..126, scaled by chaos
  return (int16_t)(((int32_t)base * s * max_q10) >> 17);
}

// Jitter a decay COEFFICIENT by perturbing its rate (65536-decay) rather than
// the near-65536 coefficient itself, so the variation lands in decay *time* and
// can't collapse the tail to a click.
static uint16_t JitterDecay(uint16_t decay, uint8_t chaos, uint8_t max_q10)
{
  uint16_t rate = 65536u - decay;                 // 1..65536 (bigger = shorter)
  int32_t nr = (int32_t)rate + ParamJitter(rate, chaos, max_q10);
  if (nr < 1) nr = 1; else if (nr > 8000) nr = 8000;
  return (uint16_t)(65536u - (uint16_t)nr);
}

// Start (or retrigger) a voice. Accent lengthens/brightens by boosting the
// initial envelope headroom. All per-hit values are latched here, jittered by
// the current chaos setting so no two hits are identical (chaos=0 => identical).
// Pitch drift is far more audible than level/length drift, so it is kept subtle
// (+/-2%) and only engages across the top ~80% of the knob; level and length
// get the full +/-20%.
static void TriggerVoice(uint8_t v, bool accent)
{
  uint8_t chaos = pattern_generator.mutable_settings()->options.drums.randomness;
  uint8_t chaos_pitch = 0;                         // gated: dead in bottom ~20%
  if (chaos > 51) { uint8_t d = chaos - 51; chaos_pitch = d + (d >> 2); } // ->0..255

  VoiceParams &p = params[v];

  int32_t amp = accent ? 0xffff : 0xc000;
  amp += ParamJitter((uint16_t)amp, chaos, 205);  // level: +/-20%
  if (amp < 0x4000) amp = 0x4000; else if (amp > 0xffff) amp = 0xffff;

  v_phase[v]      = 0;
  v_base_inc[v]   = p.base_inc + ParamJitter(p.base_inc, chaos_pitch, 20);  // +/-2%
  v_pitch_mod[v]  = p.pitch_mod0;
  v_amp[v]        = (uint16_t)amp;
  v_namp[v]       = (uint16_t)amp;
  v_amp_decay[v]  = JitterDecay(p.amp_decay,   chaos, 205);  // length: +/-20%
  v_namp_decay[v] = JitterDecay(p.noise_decay, chaos, 205);  // length: +/-20%
}

// One synth sample for all three voices -> voice_sample[]. Runs ~7.8 kHz in the
// main loop. Consumes the trigger latches first (atomically).
static void RenderVoices()
{
#ifdef DRUMSYNTH_TEST_TONE
  // Continuous 220 Hz test tone on all three jacks (bypasses everything below).
  static uint16_t tphase;
  tphase += HZ_TO_INC(220);
  int8_t t = (int8_t)S16U8MulShift8(Sine(tphase >> 8), 220);
  voice_sample[0] = t;
  voice_sample[1] = t;
  voice_sample[2] = t;
  return;
#endif

  // Consume the trigger latches (set by the Timer2 ISR); read-and-clear under
  // cli so we don't drop a trigger raised between the read and the clear.
  cli();
  uint8_t trig = v_trigger; v_trigger = 0;
  uint8_t acc  = v_accent;  v_accent  = 0;
  sei();
  for (uint8_t v = 0; v < 3; ++v) {
    if (trig & (1 << v)) {
      TriggerVoice(v, acc & (1 << v));
    }
  }

  uint8_t new_accent = 0;
  int8_t noise = (int8_t)(NextNoise() - 128);
  int16_t noise_hp = (int16_t)noise - noise_prev;   // 1st-difference high-pass
  noise_prev = noise;

  // ---- Kick: pitch-swept sine * exp amp env -----------------------------
  {
    VoiceParams &p = params[0];
    v_pitch_mod[0] = U16U16MulShift16(v_pitch_mod[0], p.pitch_decay);
    v_phase[0] += v_base_inc[0] + v_pitch_mod[0];
    v_amp[0] = U16U16MulShift16(v_amp[0], v_amp_decay[0]);
    int16_t s = S16U8MulShift8(Sine(v_phase[0] >> 8), (uint8_t)(v_amp[0] >> 8));
    voice_sample[0] = (int8_t)s;
    if (v_amp[0] > 0x1400) new_accent |= 0x08;  // accent-jack gate
  }

  // ---- Snare: tonal body (sine) + high-passed noise, separate envs -------
  {
    VoiceParams &p = params[1];
    v_phase[1] += v_base_inc[1];
    v_amp[1]  = U16U16MulShift16(v_amp[1],  v_amp_decay[1]);
    v_namp[1] = U16U16MulShift16(v_namp[1], v_namp_decay[1]);
    int16_t body  = S16U8MulShift8(Sine(v_phase[1] >> 8), (uint8_t)(v_amp[1] >> 8));
    int16_t nz    = S16U8MulShift8(noise_hp, (uint8_t)(v_namp[1] >> 8));
    int16_t s = ((body * p.tone_level) >> 8) + ((nz * p.noise_level) >> 8);
    if (s > 127) s = 127; else if (s < -128) s = -128;
    voice_sample[1] = (int8_t)s;
    if (v_amp[1] > 0x1400) new_accent |= 0x10;
  }

  // ---- Hat: high-passed noise + metallic tone, short exp env ------------
  // tone_level blends bright noise (0) <-> two-oscillator metallic "clang" (255);
  // base_inc sets the metal pitch, noise_level the overall hat level. Default
  // tone_level=0 => pure noise (unchanged from the original hat).
  {
    VoiceParams &p = params[2];
    static uint16_t hmetal_phase;
    v_namp[2] = U16U16MulShift16(v_namp[2], v_namp_decay[2]);
    uint8_t env = (uint8_t)(v_namp[2] >> 8);
    // two detuned squares (~1.625x apart) XORed -> cheap inharmonic metal tone.
    v_phase[2]   += v_base_inc[2];
    hmetal_phase += v_base_inc[2] + (v_base_inc[2] >> 1) + (v_base_inc[2] >> 3);
    int16_t metal = ((v_phase[2] ^ hmetal_phase) & 0x8000) ? 120 : -120;
    int16_t mix = (int16_t)(((int32_t)noise_hp * (255 - p.tone_level)) >> 8)
                + (int16_t)(((int32_t)metal * p.tone_level) >> 8);
    int16_t s = S16U8MulShift8(mix, env);
    s = S16U8MulShift8(s, p.noise_level);
    if (s > 127) s = 127; else if (s < -128) s = -128;
    voice_sample[2] = (int8_t)s;
    if (v_namp[2] > 0x1400) new_accent |= 0x20;
  }

  accent_bits = new_accent;
}

// Audio ISR: three 1-bit first-order sigma-delta modulators (one per drum jack)
// on the held voice samples, packed and clocked to the 595. Constant-time.
ISR(TIMER1_COMPA_vect)
{
  static uint16_t dsm0, dsm1, dsm2;
  static uint8_t decimator;

  uint8_t out = accent_bits;   // accent gates on bits 0x08/0x10/0x20

  dsm0 += (uint8_t)((uint8_t)voice_sample[0] + 128);
  if (dsm0 & 0xFF00) { out |= 0x01; dsm0 &= 0x00FF; }
  dsm1 += (uint8_t)((uint8_t)voice_sample[1] + 128);
  if (dsm1 & 0xFF00) { out |= 0x02; dsm1 &= 0x00FF; }
  dsm2 += (uint8_t)((uint8_t)voice_sample[2] + 128);
  if (dsm2 & 0xFF00) { out |= 0x04; dsm2 &= 0x00FF; }

  // Hand-written SPI to the 74HC595 (hot path — avoids a non-inlined call and a
  // full register save). Latch/SS is PB2: pulse low, clock the byte, pulse high.
  PORTB &= ~_BV(PB2);
  SPDR = out;
  while (!(SPSR & _BV(SPIF)))
    ;
  PORTB |= _BV(PB2);

  // Pace synthesis at the decimated rate; the main loop does the actual DSP.
  if (++decimator >= kSynthDecimation) {
    decimator = 0;
    ++synth_pending;
  }
}

// ===========================================================================
// Grids sequencer / clock / control (largely unchanged from Gritty-Grids)
// ===========================================================================

enum Parameter
{
  PARAMETER_NONE,
  PARAMETER_WAITING,
  PARAMETER_CLOCK_RESOLUTION,
  PARAMETER_TAP_TEMPO,
  PARAMETER_SWING,
  PARAMETER_GATE_MODE,
  PARAMETER_OUTPUT_MODE,
  PARAMETER_CLOCK_OUTPUT
};

uint32_t tap_duration = 0;
uint8_t led_pattern;
uint8_t led_off_timer;

int8_t swing_amount;

volatile Parameter parameter = PARAMETER_NONE;
volatile bool long_press_detected = false;

// Edit pages, cycled by a TAP long-hold: PERFORM (normal Grids play) -> META
// (the PARAMETER_* meta-params above) -> VOICE (drum-voice tuning) -> PERFORM.
// The clock, sequencer and audio keep running in every page so edits preview
// live; a page only changes what the six knobs edit.
enum EditPage
{
  PAGE_PERFORM,
  PAGE_META,
  PAGE_VOICE
};
volatile uint8_t edit_page = PAGE_PERFORM;
volatile uint8_t voice_edit_target = 0;   // which voice (0=BD,1=SD,2=HH) VOICE edits
volatile bool voice_target_changed = false; // TAP short-press asked to re-snapshot
const uint8_t kUpdatePeriod = F_CPU / 32 / 8000;
const uint16_t kMidiClockTimeout = 8000;

uint8_t clocked_by_midi = 0;
uint8_t mute = 0;
uint8_t external_clock = 0;
uint16_t midi_clock_timeout = 0;

// MIDI-in decode results, filled by PollMidiIn() (run every control tick) and
// consumed by HandleClockResetInputs(). Keeping a single MIDI reader lets us add
// note-in triggering without disturbing the validated clock behaviour.
volatile uint8_t midi_clock_ticks = 0;   // pending 0xF8 ticks to process
volatile bool midi_start_flag = false;   // 0xFA
volatile bool midi_continue_flag = false;// 0xFB
volatile bool midi_stop_flag = false;    // 0xFC

inline void UpdateLeds()
{
  uint8_t pattern;
  if (edit_page == PAGE_PERFORM)
  {
    if (led_off_timer)
    {
      --led_off_timer;
      if (!led_off_timer)
      {
        led_pattern = 0;
      }
    }
    if (mute)
    {
      led_pattern ^= LED_BD | LED_SD | LED_HH;
    }
    pattern = led_pattern;
    if (pattern_generator.tap_tempo())
    {
      if (pattern_generator.on_beat())
      {
        pattern |= LED_CLOCK;
      }
    }
    else
    {
      if (pattern_generator.on_first_beat())
      {
        pattern |= LED_CLOCK;
      }
    }
  }
  else if (edit_page == PAGE_VOICE)
  {
    // Voice-tuning page: LED_CLOCK steady + the selected voice's channel LED
    // blinking (~4 Hz) so it's unmistakable from the meta page. Short-press TAP
    // cycles the voice (see HandleTapButton).
    static uint16_t blink;
    ++blink;
    pattern = LED_CLOCK;
    uint8_t vled = (voice_edit_target == 0) ? LED_BD
                 : (voice_edit_target == 1) ? LED_SD
                                            : LED_HH;
    if (blink & 0x0400)
    {
      pattern |= vled;
    }
  }
  else
  {
    pattern = LED_CLOCK;
    switch (parameter)
    {
    case PARAMETER_CLOCK_RESOLUTION:
      pattern |= LED_BD >> pattern_generator.clock_resolution();
      break;

    case PARAMETER_CLOCK_OUTPUT:
      if (pattern_generator.output_clock())
      {
        pattern |= LED_ALL;
      }
      break;

    case PARAMETER_SWING:
      if (pattern_generator.swing())
      {
        pattern |= LED_ALL;
      }
      break;

    case PARAMETER_OUTPUT_MODE:
      if (pattern_generator.output_mode() == OUTPUT_MODE_DRUMS)
      {
        pattern |= LED_ALL;
      }
      break;

    case PARAMETER_TAP_TEMPO:
      if (pattern_generator.tap_tempo())
      {
        pattern |= LED_ALL;
      }
      break;

    case PARAMETER_GATE_MODE:
      if (pattern_generator.gate_mode())
      {
        pattern |= LED_ALL;
      }
    }
  }
  leds.Write(pattern);
}

// MIDI note velocity. When midi_accent_velocity is true, accented drum steps
// are sent at kVelocityAccent and unaccented ones at kVelocityNormal; when
// false (or in a mode without accents), every note is sent at kVelocityAccent.
// Only settable by recompiling for now, but kept as a variable so it can later
// be toggled at runtime (e.g. from the panel controls or a SysEx message).
bool midi_accent_velocity = true;
const uint8_t kVelocityAccent = 127;
const uint8_t kVelocityNormal = 90;

inline uint8_t NoteVelocity(bool has_accents, uint8_t accented)
{
  return (midi_accent_velocity && has_accents && !accented) ? kVelocityNormal : kVelocityAccent;
}
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
int main(void)
{
  ResetWatchdog();
  Init();
  clock.Update(120, pattern_generator.clock_resolution());

  while (1)
  {
    // Render the synth samples the audio ISR has queued, but only a bounded
    // batch per iteration so ScanPots() always gets to run — otherwise, if the
    // synth ever can't quite keep up, synth_pending pins high and the pattern
    // knobs (read in ScanPots) go dead. If the synth briefly lags it just plays
    // catch-up; the knobs stay responsive.
    uint8_t budget = 8;
    while (synth_pending && budget--)
    {
      RenderVoices();
      cli();
      --synth_pending;
      sei();
    }

    ScanPots();

    // Non-blocking MIDI-out: send a byte ONLY when the UART is ready, so a
    // multi-note burst never stalls the loop (which would starve the synth and
    // click the audio). We loop back and service synth_pending immediately.
    if (buffer_tail != buffer_head && (UCSR0A & _BV(UDRE0)))
    {
      UDR0 = output_buffer[buffer_tail];
      buffer_tail = (buffer_tail + 1) % MIDI_BUFFER_SIZE;
    }
  }
}

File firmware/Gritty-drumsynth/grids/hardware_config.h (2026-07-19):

// Copyright 2012 Emilie Gillet.
//
// Author: Emilie Gillet (emilie.o.gillet@gmail.com)
//
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
#ifndef GRIDS_HARDWARE_CONFIG_H_
#define GRIDS_HARDWARE_CONFIG_H_

#include "avrlib/base.h"
#include "avrlib/gpio.h"
#include "avrlib/parallel_io.h"
#include "avrlib/serial.h"
#include "avrlib/spi.h"

namespace grids
{

  enum AdcChannel
  {
    ADC_CHANNEL_X_CV,
    ADC_CHANNEL_Y_CV,
    ADC_CHANNEL_RANDOMNESS_CV,
    ADC_CHANNEL_BD_DENSITY_CV,
    ADC_CHANNEL_SD_DENSITY_CV,
    ADC_CHANNEL_HH_DENSITY_CV,
    ADC_CHANNEL_TEMPO,
    ADC_CHANNEL_LAST
  };

  enum LedBits
  {
    LED_CLOCK = 1,
    LED_BD = 8,
    LED_SD = 4,
    LED_HH = 2,
    LED_ALL = LED_CLOCK | LED_BD | LED_SD | LED_HH
  };

  enum InputBits
  {
    INPUT_CLOCK = 2,
    INPUT_RESET = 4,
    INPUT_SW_RESET = 8
  };

  using avrlib::DigitalInput;
  using avrlib::Gpio;
  using avrlib::ParallelPort;
  using avrlib::PortB;
  using avrlib::PortD;
  using avrlib::Serial;
  using avrlib::SerialPort0;
  using avrlib::SpiMaster;
  // using avrlib::BufferedSoftwareSerialOutput;

  typedef ParallelPort<PortD, avrlib::PARALLEL_NIBBLE_HIGH> Leds; // D4, D5, D6, D7

  // Replaced by GPIOs below, since D1 in now used for MIDI OUT (on SerialPort0/TX/D1)
  // typedef ParallelPort<PortD, avrlib::PARALLEL_NIBBLE_LOW> Inputs;  // (D0), D1, D2, D3

  // ---- Pinout selection -----------------------------------------------------
  // triggerspace moves the clock input off D1 (PD1) onto D8 (PB0) so the hardware
  // UART on D0/D1 (PD0/PD1) is free for TRS-A MIDI in/out. Original Grids hardware
  // (and clones) instead wire the clock to D1 and have no MIDI. To build for that
  // original hardware, set TRIGGERSPACE_PINOUT to 0: the clock input moves back to
  // D1 — but then D0/D1 are no longer a spare UART, so MIDI I/O is unavailable.
  // Leave it 1 for triggerspace. This is the only pin that actually moved; D2/D3
  // (reset/tap) are the same on both.
  #define TRIGGERSPACE_PINOUT 1

  typedef Gpio<PortD, 2> _resetPin;  // D2 (PD2)
  typedef Gpio<PortD, 3> _buttonPin; // D3 (PD3)
#if TRIGGERSPACE_PINOUT
  typedef Gpio<PortB, 0> _clockPin;  // D8 (PB0) — triggerspace (moved off D1)
#else
  typedef Gpio<PortD, 1> _clockPin;  // D1 (PD1) — original Grids clock input
#endif

  typedef DigitalInput<_resetPin> ResetInput;   // D2 (PD2)
  typedef DigitalInput<_buttonPin> ButtonInput; // D3 (PD3)
  typedef DigitalInput<_clockPin> ClockInput;   // D8/D1 per TRIGGERSPACE_PINOUT

  typedef SpiMaster<Gpio<PortB, 2>, avrlib::MSB_FIRST, 2> ShiftRegister;

  // MIDI serial is now in and out (PD0/PD1)
  typedef Serial<SerialPort0, 31250, avrlib::POLLED, avrlib::POLLED, false> MidiIO;

} // namespace grids

#endif // GRIDS_HARDWARE_CONFIG_H_

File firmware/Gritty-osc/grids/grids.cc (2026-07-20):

// Gritty-osc — Milestone 6: six-voice DDS chord oscillator.
//
// Six independent DDS voices, each a 16-bit phase accumulator, packed into the
// six audio bits of the 74HC595 and shifted out once per sample tick. Bit map
// matches the Grids state byte / triggerspace jack wiring:
//   voice 0 -> 0x01 CH1        voice 3 -> 0x08 CH1_ACC
//   voice 1 -> 0x02 CH2        voice 4 -> 0x10 CH2_ACC
//   voice 2 -> 0x04 CH3        voice 5 -> 0x20 CH3_ACC
// Bit 0x40 (CH_CLOCK jack) carries a first-order sigma-delta PDM *mix* of all six
// voices; bit 0x80 (CH_RND) is left alone. (Those two jacks double as MIDI I/O —
// the mix is only reachable with the CLOCK jack jumpered to voltage-trigger mode.)
//
// Control (default = Option B; see OSC_DENSITY_AS_PITCH below to switch):
//   Y knob/CV       -> root pitch
//   chaos knob/CV   -> chord type (8: unison-superpulse/power/maj/min/sus4/…)
//   BD/SD/HH knobs  -> per-channel PWM duty of the three chord tones
//   X knob/CV       -> detune (1st half: sub-octaves; 2nd half: adds the mains)
//   CLOCK/RESET/btn -> trigger function: arp / rotate / pluck (see OSC_TRIG_*)
//   TEMPO           -> arp range 1..4 octaves (OSC_TRIG_ARP only)
//   voices 3/4/5    -> sub-octaves of voices 0/1/2 (so all six sound)
//
// Dropped to 16-bit accumulators + Fs = 62.5 kHz so six voices fit the ISR
// budget at 16 MHz (see plans/gritty-osc.md, Milestone 4).
//
// M5: pitch comes from a precomputed note -> tuning-word table (equal
// temperament, generated for Fs = 62.5 kHz), so no powf()/float is used at
// runtime — a plain flash lookup replaces the per-change float pow.
//
// M7 (optional, build-time): MIDI note control. Define one of the OSC_MIDI_*
// modes below to play the six voices from the D0/D1 TRS-A MIDI input instead of
// the knob/CV + trigger control — a one-key chord, three MIDI channels, 3- or
// 6-voice polyphony, or a split keyboard. Requires TRIGGERSPACE_PINOUT (so that
// D0/D1 are free as a UART).
//
// Fork of Gritty-Grids, based on Mutable Instruments' Grids (Emilie Gillet).
// GPLv3 (see LICENSE).

#include <avr/interrupt.h>
#include <avr/pgmspace.h>

#include "avrlib/adc.h"
#include "avrlib/watchdog_timer.h"

#include "grids/hardware_config.h"

// ---- MIDI note control (build-time) --------------------------------------
// Define exactly ONE of these to turn the module into a MIDI-controlled
// oscillator (needs TRIGGERSPACE_PINOUT — MIDI lives on the D0/D1 UART). With
// none defined the knob/CV + trigger control is used and MIDI is off.
//   OSC_MIDI_MONO_ROOT  (A) one channel; the (last) held note sets the ROOT and
//                           the panel still shapes it — chaos = chord type,
//                           X = detune, density knobs = per-channel PWM. A whole
//                           6-voice chord from a single key.
//   OSC_MIDI_MULTI_3CH  (B) three channels (base, base+1, base+2) drive osc
//                           0/1/2 independently; each sub tracks its main an
//                           octave down. Mod wheel (CC1) = global PWM; CC94 =
//                           detune depth.
//   OSC_MIDI_POLY3      (C1) 3-voice polyphony, round-robin over osc 0/1/2; each
//                           sub doubles its main an octave down. Mod wheel = PWM.
//   OSC_MIDI_POLY6      (C2) 6-voice polyphony, round-robin over all six oscs
//                           (subs are independent voices, no doubling).
//   OSC_MIDI_SPLIT      (D) split keyboard: notes >= OSC_SPLIT_NOTE round-robin
//                           over the mains (0/1/2); notes below are a bassline
//                           round-robined over the subs (3/4/5).
//#define OSC_MIDI_MONO_ROOT
//#define OSC_MIDI_MULTI_3CH
//#define OSC_MIDI_POLY3
//#define OSC_MIDI_POLY6
//#define OSC_MIDI_SPLIT

// Base MIDI channel (0-based: 0 = channel 1). Mode B also uses base+1, base+2.
#ifndef OSC_MIDI_CHANNEL
#define OSC_MIDI_CHANNEL 0
#endif
// Split point for OSC_MIDI_SPLIT, as a MIDI note number (60 = middle C = C4).
// 48 = C3: notes >= this play the mains, below play the sub/bass voices. Try 60.
#ifndef OSC_SPLIT_NOTE
#define OSC_SPLIT_NOTE 48
#endif
// Per-note LED flash length, in main-loop iterations (approximate — the loop
// rate varies a little by mode). The firing channel's LED blinks this long on
// each note-on; in the round-robin modes you see the LEDs cycle BD/SD/HH.
#ifndef OSC_LED_FLASH_LOOPS
#define OSC_LED_FLASH_LOOPS 500
#endif

#if defined(OSC_MIDI_MONO_ROOT) || defined(OSC_MIDI_MULTI_3CH) || \
    defined(OSC_MIDI_POLY3) || defined(OSC_MIDI_POLY6) || defined(OSC_MIDI_SPLIT)
#define OSC_MIDI
#endif
#if defined(OSC_MIDI) && !TRIGGERSPACE_PINOUT
#error "OSC_MIDI needs the D0/D1 UART; build with TRIGGERSPACE_PINOUT 1."
#endif
#ifdef OSC_MIDI
#include "grids/midi.h"
#endif

using namespace avrlib;
using namespace grids;

ShiftRegister shift_register;
AdcInputScanner adc;
ClockInput clock_input;   // D8 (PB0) trigger in -> "step" (advance)
ResetInput reset_input;   // D2 trigger in       -> "reset"
ButtonInput button_input; // D3 button           -> cycle arp mode (or manual step)
Leds leds;                // D4..D7 -> arp-mode readout
#ifdef OSC_MIDI
MidiIO midi;              // D0/D1 TRS-A MIDI (input used; output unused here)
#endif

static const uint8_t kNumVoices = 6;

// The three "density/fill" pots, used as per-channel PWM (and pitch in the
// OSC_DENSITY_AS_PITCH / mode-A layouts). File scope so RenderMidi() shares them.
static const uint8_t kDensityCh[3] = {
    ADC_CHANNEL_BD_DENSITY_CV,
    ADC_CHANNEL_SD_DENSITY_CV,
    ADC_CHANNEL_HH_DENSITY_CV};

// ---- Control layout (build-time) -----------------------------------------
// Default (Option B): Y = root pitch, chaos = chord type, the three density/fill
// knobs = per-channel PWM, X = detune (movement), TEMPO reserved. Define
// OSC_DENSITY_AS_PITCH to instead make the density knobs independent per-channel
// pitch (the M5 layout): TEMPO = transpose, X = global PWM, Y/chaos unused.
//#define OSC_DENSITY_AS_PITCH

// ---- Trigger function (CLOCK D8 / RESET D2 / button D3) -------------------
// CLOCK and the button both fire "step"; RESET fires "reset". Pick exactly one
// behaviour (Option B builds only; ignored under OSC_DENSITY_AS_PITCH):
//   ARP    - CLOCK steps through the chord tones across octaves (chord = the
//            pool); all six voices play the stepping note. TEMPO = range (1..4
//            octaves). The BUTTON cycles direction mode (up / down / up-down inc /
//            up-down exc / random / random-walk), shown on the LEDs as 1..6.
//   ROTATE - keep the chord sounding; each step rotates the voicing/inversion.
//   PLUCK  - keep the chord sounding; each step fires a decaying PWM-duty
//            envelope (a percussive re-articulation).
#define OSC_TRIG_ARP
//#define OSC_TRIG_ROTATE
//#define OSC_TRIG_PLUCK
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

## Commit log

2023-03-12 Clean front panel changes
    [Panel Clean.kicad_pcb]
2023-08-20 Updated with MIDI-TRS ports, numerous tweaks.
    Moved front panel into main PCB design, remove old panels and gerbers that will no longer fit this design.
    [NanoGris-B_Cu.gbr, NanoGris-B_Mask.gbr, NanoGris-B_Paste.gbr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]
2023-08-27 Change MIDI ports to reuse clock out/rnd out ports.
    Jumpers to select if we use MIDI or clock out / rnd.
    Moved FILL knobs to a more ergonomic arrangement.
    General polish to front panel.
    [NanoGris.kicad_pcb, NanoGris.kicad_sch]
2023-08-27 Generate iBOM.
    Exclude some extraneous items from the BOM.
    [NanoGris.kicad_pcb]
2023-08-27 Remove soldermask layers over front panel.
    We will go for a black panel in the first instance, since it seems the gerber viewer doesn't render the silkscreen when it's not on top of solder mask. For JLC bare aluminium panels we should cut the silkscreen layer out of the soldermask rectangle(s) (eg, difference in Inkscape) so that our solder mask doesn't cover the silkscreen.
    [NanoGris.kicad_pcb]
2023-08-27 Generate gerbers and black/white front panel.
    [bom.csv, designators.csv, positions.csv]
2023-08-27 Remove unused files.
    Old BOM and older KiCad files.
    [GrisNano.csv, NanoGris.sch]
2023-08-27 Change naming to 'triggerspace' in most places
    [triggerspace.kicad_pcb, triggerspace.kicad_sch]
2024-12-31 v0.042 release.
    Update README with build notes.
    Add schematic pdf.
    KiCad files re-saved with version 8.0
    [triggerspace.kicad_pcb, triggerspace.kicad_sch]
2026-07-18 Gritty-osc M2: single-voice DDS square oscillator (16MHz)
    - Replace the drum firmware with a DDS square-wave oscillator: Timer2 CTC
    100kHz sample clock, 32-bit phase accumulator, MSB -> 74HC595 BD bit.
    - TEMPO knob -> equal-tempered pitch A1..G#6 (hand-optimised ISR, ~120 cyc).
    - Build for F_CPU=16000000 (this board's real clock; verified in tune on
    hardware: A3=220Hz, A4=440Hz, G#6=1661.9Hz).
    [grids.cc]
2026-07-18 Gritty-osc M3: PWM duty control on X-CV knob
    Add pulse-width (duty) control to the single-voice DDS oscillator: the ISR
    now emits high while phase < duty, and the X-CV knob sweeps ~12%..88% duty
    (centred on 50% = square). Extremes are trimmed so the whole knob throw stays
    audible. Also refresh stale 20 MHz / Milestone 2 comments to 16 MHz / M3.
    [grids.cc]
2026-07-18 Gritty-osc M4: six-voice DDS oscillator packed to the 595
    Six independent 16-bit DDS voices packed into the six audio bits of the
    74HC595 (CH1/2/3 + CH1/2/3_ACC), shifted out each sample tick. Dropped to
    16-bit accumulators and Fs=62.5kHz so all six fit the ISR budget at 16MHz
    (profiled ~190/256 cycles). Interim control: density knobs -> voices 0/1/2
    pitch (reversed, matching stock ~pot wiring), accents track one octave down,
    TEMPO -> +/-2oct transpose, X -> global PWM duty.
    [grids.cc]
2026-07-18 Gritty-osc: PDM mix of all six voices on the clock-out jack
    Sum the six voice levels (0..6) each sample and run a first-order sigma-delta
    modulator to emit a 1-bit PDM stream on 74HC595 bit 0x40 (CH_CLOCK jack), whose
    pulse density tracks the mix. Low-passed downstream it reconstructs a mono sum
    of all six squares; raw it has a HF 'sizzle' that pairs well with an external
    low-pass. Only reachable with the CLOCK jack jumpered to voltage-trigger mode.
    Tried a second-order loop for cleaner noise shaping but it overloads and
    crackles on loud input (would need state clamping); first order is
    unconditionally stable, so kept that.
    [grids.cc]
2026-07-18 Gritty-osc M5: note-LUT tuning, drop powf/float
    Replace the per-change powf() pitch calc with a 128-entry PROGMEM note ->
    tuning-word table (equal temperament, generated for Fs=62.5kHz). Runtime is now
    a plain flash lookup with index clamping; no float is used anywhere, so libm
    soft-float drops out and flash shrinks ~3162 -> ~1298 bytes. Tuning is identical
    (same rounded tuning words the float path produced).
    [grids.cc]
2026-07-18 Gritty-osc M6: chord engine, detune, and configurable trigger (arp)
    Turn the six-voice oscillator into a chord oscillator (Option B mapping):
    - Y = root pitch, chaos = chord type (8: unison-superpulse/power/maj/min/sus4/
    maj7/min7/quartal), density knobs = per-channel PWM.
    - X = two-phase detune: sub-octaves spread across the whole throw, mains only
    past the halfway point -> ensemble/supersaw shimmer. Chord 0 = 6-voice unison
    'superpulse'.
    - Build-time OSC_DENSITY_AS_PITCH restores independent per-channel pitch.
    Trigger inputs (CLOCK D8 / RESET D2 / button D3), build-selectable:
    - OSC_TRIG_ARP (default): CLOCK steps the arp through the chord tones across
    octaves (all voices play the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
    [grids.cc]
2026-07-19 Gritty-osc: add build-time MIDI note-control modes
    Play the six DDS voices from the D0/D1 TRS-A MIDI input via one of five
    build-time modes (all off by default = the knob/arp oscillator):
    A OSC_MIDI_MONO_ROOT one channel -> full 6-voice chord engine (panel
    still shapes chord/detune/PWM)
    B OSC_MIDI_MULTI_3CH channels base..base+2 -> osc 0/1/2; sub = octave down
    C1 OSC_MIDI_POLY3 3-voice round-robin; subs double their main -1 oct
    C2 OSC_MIDI_POLY6 6-voice round-robin; subs independent
    D OSC_MIDI_SPLIT notes >= OSC_SPLIT_NOTE -> mains, below -> sub bass
    Polled parser in the main loop (running status, note on/off, CC1 mod-wheel
    -> global PWM, CC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
    [grids.cc, hardware_config.h]
2026-07-19 Gritty-drumsynth: synthesised drum voices, tuning UI, docs
    Replace the raw voltage-trigger outputs with three internally synthesised
    808/909-style voices rendered as 1-bit PDM on the BD/SD/HH jacks:
    - Timer1 audio ISR (Fs 31.25 kHz) runs one sigma-delta modulator per jack;
    heavy DSP amortised in the main loop at Fs/4 ~= 7.8 kHz (zero-order held).
    - Kick (pitch-swept sine), snare (sine body + HP LFSR noise), hat (HP noise
    + cheap two-oscillator metallic tone blended by tone_level).
    - Per-hit humanisation from the PERFORM Randomness knob: pitch +/-2% (gated to
    the top ~80%), level & decay-length +/-20%.
    - Three-page edit UI (long-hold TAP: PERFORM -> META -> VOICE); voice params
    persi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
    [grids.cc, hardware_config.h]
2026-07-19 Hardware: PCB layout revision, aluminium front-panel gerbers, panel SVG
    Update the main PCB layout, add the aluminium front-panel fabrication
    outputs (production/front_panel_aluminium/) and panel cutout artwork (svg/).
    README roadmap notes: LPZW_TRS_MIDI dual-type-A/B option; fix a typo.
    (PCB layout authored in KiCad; committed as-is.)
    [triggerspace-B_Cu.gbl, triggerspace-B_Mask.gbs, triggerspace-B_Paste.gbp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]
2026-07-20 Gritty-osc: blink the firing channel's LED on each MIDI note
    Each note-on reloads a per-channel flash timer (OSC_LED_FLASH_LOOPS loops),
    counted down in the main loop while lighting that channel's LED (BD/SD/HH).
    Round-robin allocation therefore reads as the LEDs cycling; mode A blinks all
    three together. Clock-jack mix (ISR bit 0x40) is untouched. Regenerated the
    per-mode hexes.
2026-08-18 Hardware: socketed RC reconstruction caps on the six output jacks
    Adds J16..J21 (2.54mm 1x02 sockets) on the jack PCB's back copper, one per
    audio output jack. Pin 1 taps the channel net on the jack side of the 1k
    series resistor (R32..R37 on the back board); pin 2 lands in the GND pour.
    Plugging a capacitor in forms a first-order reconstruction low-pass with the
    existing 1k; pulling it out disables the filter, so the cap value stays a
    run-time choice rather than a layout commitment.
    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
    [triggerspace.kicad_pcb, triggerspace.kicad_sch]
2026-08-19 Fixed cap socket placement by hand
    [triggerspace.kicad_pcb, triggerspace.kicad_sch]
2026-08-19 Bump version to v0.5.0, regenerate back_pcb/jack_pcb fab outputs
    Version bump (schematic title-block rev, PCB silkscreen text on both boards)
    reflects the RC reconstruction-cap sockets added on the jack PCB's six audio
    outputs. README documents the new revision as pending bench verification,
    keeping the v0.042 notes as historical build/bodge record.
    Regenerated gerbers, drill, position files, netlist, and BOM for back_pcb and
    jack_pcb to pick up the cap-socket placement fix and the new silkscreen text.
    [bom.csv, designators.csv, positions.csv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]
2026-10-03 Nano VIN from +12V, LED resistors, MIDI header labels/refdes, fix fab outputs
    - A1 VIN (pin 30) moved from +5V to +12V, removing the v0.042 bodge. The +5V
    rail junction moves off pad 30 to a new via; VIN is routed on B.Cu to U4 IN.
    - R25-R28 (LED resistors) 100r -> 4.7k, with "RL" silkscreen labels.
    - Back-board 2-pin MIDI socket: was a PCB-only footprint duplicating the jack
    board's J4. Renamed J9 and added to the schematic on IN_MIDI/OUT_MIDI.
    Front D0/RX and D1/TX labels were swapped; corrected, and MIDI IN/OUT
    labels added on the back silkscreen.
    - Regenerated back_pcb/jack_pcb fab outputs. The previous v0.5.0 outputs
    included the other board's tracks, vias and zones in each zi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
    [bom.csv, designators.csv, positions.csv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]
2026-10-03 U4 lies flat (TO-220 tab-down), back PCB outline shifted 1mm
    - U4 (L7805) swapped to TO-220-3_Horizontal_TabDown, pin 1 at (165.0, 78.5),
    body lying over the free area above J7. Only the GND pour is on F.Cu under
    the tab (with GND stitching vias); +5V/+12V rerouted on B.Cu or between the
    pin row and the body. C12 moved up 0.94mm to make room.
    - Back PCB outline (and its zones) moved 1mm (-x in the file, right as seen
    from the front panel). Parts and inter-board headers are unchanged; checked
    against all 33 mating header/standoff pins that the left edge is now flush
    with the jack PCB to within 0.09mm.
    - Regenerated back_pcb/jack_pcb fab outputs.
    [bom.csv, positions.csv, triggerspace.kicad_pcb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]
2026-10-03 Regenerate schematic PDF and iBOM for v0.5.0
    iBOM built with InteractiveHtmlBom v2.12.0 (the installed v2.6.0 plugin
    fails on KiCad 9.0.9), using the same display settings as before.
2026-10-03 LPZW auto-crossover MIDI IN (TRS Type A/B) with SOIC-8 and 6N138 build options
    U8 becomes an HCPL-2630 dual optocoupler wired as the LPZW auto-crossover
    MIDI input (Kay Knofe / LPZW.modules, credited on the jack PCB silkscreen):
    two anti-parallel LEDs across tip and ring with their own 220R (R48, new
    R51), wire-ORed open-collector outputs, pull-up R47 220R -> 1k.
    - U9: optional HCPL-0630 SOIC-8 footprint inside U8's DIP-8 footprint
    - JP3/JP4 3-pad solder jumpers (1-2 bridged) and optional D7 keep a
    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
    [triggerspace.kicad_pcb, triggerspace.kicad_sch]
2026-10-03 README: Jumpers section with annotated PCB diagrams
    Describes JP1/JP2/J1/J2 (stock firmware re-routing), J5/J6/J8/J3/J4 (CLOCK/RND
    jacks as MIDI ports or trigger outputs), J9 and the JP3/JP4 optocoupler
    selection, with renders of the back and jack PCBs in images/jumpers/.
2026-10-04 D8: optional 5.1V zener footprint as an alternative to U5 (LM4040LP-5)
    Upright DO-35 footprint inside U5's outline, cathode to GND, anode on the
    -5V ref_5 rail; ref_5 re-routed locally around it. README build option and
    CHANGELOG entry.
    [triggerspace.kicad_pcb, triggerspace.kicad_sch]
2026-10-04 +5V supply options: JP5 (Nano regulator), JP6 (Eurorack +5V), 16-pin J12
    - JP5 (open) links the Nano's 5V pin (A1 pin 27) to the +5V rail
    - J12 becomes a 2x8 footprint (a 2x5 header still fits pins 1-10); pins 11/12
    (Eurorack +5V) reach the +5V rail through JP6 (open), pins 13-16 unconnected
    - U4, C11, C12 marked OPTIONAL on the silkscreen
    - D5 moved left, R29 upright (2.54mm), power tracks around J12 re-routed;
    zones refilled with the project's rules
    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
    [triggerspace.kicad_pcb, triggerspace.kicad_sch]
2026-10-04 Regenerate fab outputs, schematic PDF and iBOM
    Gerbers, drill, positions, IPC-D-356, designators and per-board BOMs for the
    back and jack PCBs, after the LPZW MIDI IN, D8 zener and +5V supply changes.
    [bom.csv, designators.csv, positions.csv]
2026-10-04 Tidy +5V trace from JP6 on the back PCB; refill zones
    [triggerspace.kicad_pcb]
2026-10-04 Firmware: MIDI accent velocity in Gritty-Grids and Gritty-drumsynth
    - Gritty-Grids submodule -> 510c06e: accented steps sent at velocity 127,
    unaccented at 90 (midi_accent_velocity, default true), accents decoded
    per output mode
    - Gritty-drumsynth: same MIDI note-out change; the voices' accent layer now
    uses the same accent decoding, so Euclidean reset pulses and the clock-mode
    reset bit no longer trigger accents
    - README: accent -> MIDI handling documented in Firmware; velocity idea
    removed from TODO
    [grids.cc]

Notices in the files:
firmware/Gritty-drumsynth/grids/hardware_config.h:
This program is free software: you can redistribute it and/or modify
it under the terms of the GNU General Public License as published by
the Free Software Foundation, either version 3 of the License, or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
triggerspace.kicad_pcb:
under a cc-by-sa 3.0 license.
